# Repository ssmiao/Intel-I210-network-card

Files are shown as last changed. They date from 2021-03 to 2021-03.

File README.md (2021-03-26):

# Intel-I210-network-card
This is a standard PCIe x1 Ethernet Card designed by KiCad.

Before you make it and want to use in your computer, remember to go to DOS system and flash config file to the card. The following steps maybe help.

1. Download [This folder](https://github.com/ssmiao/Intel-I210-network-card)  

2. Use Rufus to create a FreeDOS USB disk (RuFus support itself, you don't need to download a ISO file or something).
3. Copy my folder to the disk.
4. Shutdown the computer and insert the network card
5. Start the computer into FreeDOS system.
6. Go to /FARTHING and run AUTO.BAT

Good luck since I design it 1 year ago and can't remember it clearly. But the hardware can work.

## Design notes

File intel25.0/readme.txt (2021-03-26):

Intel(R) Network Connections Software Version 25.0 Release Notes
================================================================
January 2, 2020

This release includes software and drivers for Intel(R) adapters and integrated 
network connections.

Contents
========

- What's New in This Release
- Discontinued Support
- Configuring SR-IOV for improved network security
- Operating System Support
- Installing Drivers and Intel(R) PROSet for Windows* Device Manager
- User Guides
- Intel Fiber Optic Adapters
- Saving and Restoring Adapter Settings in Microsoft Windows operating systems
- Teaming Notes
- Jumbo Frames
- Power Management and System Wake
- RDMA (Remote Direct Memory Access) Notes
- Microsoft* Windows* 8.1 and Windows Server* 2012 R2 Notes
- Microsoft* Windows Server* 2012 Notes
- Microsoft* Windows* 7 and Windows Server* 2008 R2 Notes
- Intel(R) 710 Series Network Controller Notes
- Intel(R) 10GbE Network Adapter Notes
- Quad Port Server Adapter Notes
- Intel(R) Ethernet Desktop Adapter and Network Connection Notes
- Known Issues
- Customer Support

What's New in This Release
==========================

- Support for the Intel(R) Ethernet Network Adapter X710-T2L for OCP 3.0
- Support for the Intel(R) Ethernet Network Adapter X710-T4L for OCP 3.0

Discontinued Support
====================
Release 24.4 removes the following from the installation package:
- Support for PRO/100 devices
- DOS drivers
- UEFI driver support for PCI/PCI-X devices
- Support for WinCE
- Microsoft* Windows* 10 RS3 (NDIS65) Universal Drivers. Please use the NDIS68 
drivers.
- Support for FCoE
Note: Upgrading to Release 24.4 or later will automatically remove FCoE if it 
was installed in a previous release. Please see BootUtil.txt if you use FCoE 
Boot.

i40evf and ixlv drivers renamed to iavf
---------------------------------------
Release 24.0 renames the i40evf and ixlv drivers to iavf. The i40evf and ixlv 
drivers have been removed from this install media. The iavf drivers can be 
found in the PROAVF directory of this install media.

Discontinued operating systems
------------------------------
Release 24.0 is the last release that supports the following operating systems:
- VMWare* ESX* 6.0 VMKLinux drivers
- VMWare ESX 5.0/5.1

Itanium(R)-based systems are no longer supported
------------------------------------------------
Release 23.5 is the last release that contains any support for Itanium(R)-based 
systems.

Unsupported devices and adapters
--------------------------------
Starting with Release 23.5, the drivers for the following adapters and devices 
will no longer be tested or updated. The drivers may still be provided in your 
download package or on your install media for your convenience.
- Intel(R) 82566MM Gigabit Network Connection
- Intel(R) PRO/1000 PB Dual Port Server Connection
- Intel(R) PRO/1000 EB Network Connection with I/O Acceleration
- Intel(R) PRO/1000 EB1 Network Connection with I/O Acceleration
- Intel(R) PRO/1000 EB Backplane Connection with I/O Acceleration
- Intel(R) 82567V-3 Gigabit Network Connection
- Intel(R) 82567V-4 Gigabit Network Connection
- Intel(R) 82567LM-4 Gigabit Network Connection
- Intel(R) 82567LF Gigabit Network Connection
- Intel(R) 82567V Gigabit Network Connection
- Intel(R) 82567LM-2 Gigabit Network Connection
- Intel(R) 82567LF-2 Gigabit Network Connection
- Intel(R) 82567V-2 Gigabit Network Connection
- Intel(R) 82567LM-3 Gigabit Network Connection
- Intel(R) 82567LF-3 Gigabit Network Connection
- Intel(R) 82577LM Gigabit Network Connection
- Intel(R) 82577LC Gigabit Network Connection
- Intel(R) 82578DM Gigabit Network Connection
- Intel(R) 82578DC Gigabit Network Connection
- Intel(R) 82567LM Gigabit Network Connection
- Intel(R) 82566DM Gigabit Network Connection
- Intel(R) 82566DC Gigabit Network Connection
- Intel(R) 82566MC Gigabit Network Connection
- Intel(R) PRO/1000 PT Dual Port Network Connection
- Intel(R) PRO/1000 PT Dual Port Server Adapter
- Intel(R) PRO/1000 PT Dual Port Server Connection
- Intel(R) PRO/1000 PF Dual Port Server Adapter
- Intel(R) PRO/1000 PT Network Connection
- Intel(R) PRO/1000 PT Server Adapter
- Intel(R) PRO/1000 PF Network Connection
- Intel(R) PRO/1000 PF Server Adapter
- Intel(R) PRO/1000 PB Server Connection
- Intel(R) PRO/1000 PM Network Connection
- Intel(R) PRO/1000 PL Network Connection
- Intel(R) PRO/1000 PT Quad Port Server Adapter
- Intel(R) PRO/1000 PF Quad Port Server Adapter
- Intel(R) PRO/1000 PT Desktop Adapter
- Intel(R) PRO/1000 EB1 Backplane Connection with I/O Acceleration
- Intel(R) PRO/1000 PT Quad Port LP Server Adapter
- Intel(R) 82566DM-2 Gigabit Network Connection
- Intel(R) 82562V 10/100 Network Connection
- Intel(R) 82562V-2 10/100 Network Connection
- Intel(R) 82562G-2 10/100 Network Connection
- Intel(R) 82562GT-3 10/100 Network Connection
- Intel(R) 82562GT-2 10/100 Network Connection
- Intel(R) 82562GT 10/100 Network Connection
- Intel(R) 82562G 10/100 Network Connection
- Intel(R) Gigabit PT Quad Port Server ExpressModule
- Intel(R) 82566DC-2 Gigabit Network Connection
- Intel(R) 82598EB 10 Gigabit AF Dual Port Network Connection
- Intel(R) 10 Gigabit XF SR Dual Port Server Adapter
- Intel(R) 10 Gigabit XF SR Server Adapter
- Intel(R) 82598EB 10 Gigabit AF Network Connection
- Intel(R) 10 Gigabit AT Server Adapter
- Intel(R) 82598EB 10 Gigabit AT Network Connection
- Intel(R) 10 Gigabit AT2 Server Adapter
- Intel(R) 82598EB 10 Gigabit AT2 Network Connection
- Intel(R) 82598EB 10 Gigabit AT CX4 Network Connection
- Intel(R) 10 Gigabit SR Dual Port Express Module
- Intel(R) 10 Gigabit CX4 Dual Port Server Adapter
- Intel(R) 82598EB 10 Gigabit KX4 Network Connection
- Intel(R) 10 Gigabit AF DA Dual Port Server Adapter
- Intel(R) 10 Gigabit XF LR Server Adapter
- Intel(R) 82598EB 10 Gigabit Dual Port Network Connection

Configuring SR-IOV for improved network security
================================================

In a virtualized environment, on Intel(R) Server Adapters that support SR-IOV, 
the virtual function (VF) may be subject to malicious behavior. 
Software-generated frames are not expected and can throttle traffic between the 
host and the virtual switch, reducing performance. To resolve this issue, 
configure all SR-IOV enabled ports for VLAN tagging. This configuration allows 
unexpected, and potentially malicious, frames to be dropped.

Operating System Support
========================

NOTE: Before performing a major OS upgrade, Intel recommends that you uninstall 
the Intel PROSet feature, perform the OS upgrade, and then reinstall with the 
latest version of Intel PROSet. This will ensure all features are available and 
avoid potential issues.

NOTE: Microsoft* Windows Server* 2012 R2 is the last Windows Server operating 
system version that supports Intel(R) Advanced Networking Services (Intel ANS).

NOTE: Intel(R) PROSet for Windows* Device Manager is not supported on 
Microsoft* Windows Server* 2019 (and later) and Microsoft Windows* 10 Version 
1809 (and later). Use Intel(R) PROSet Adapter Configuration Utility instead. 
The installer will determine which utility to install based on the operating 
system you are running.

Intel 10GbE Ethernet Adapters do not support Microsoft* Windows* 32-bit 
operating systems. They support 32-bit versions of Linux* and FreeBSD*.

Even though the UEFI driver states that it supports "Intel(R) 40GbE" devices, 
the driver supports all devices based on the Intel(R) X722, XXV710, X710, and 
XL710 controllers, regardless of speed.

Drivers and Software for unsupported operating systems
------------------------------------------------------
The most recent software and drivers for unsupported operating systems can be 
found on the Intel Customer Support website at
http://www.intel.com/support/go/network/adapter/home.htm

Some older Intel(R) Ethernet Adapters do not have full software support for the 
most recent versions of Microsoft Windows*. Many older Intel Ethernet Adapters 
have base drivers supplied by Microsoft Windows. Lists of supported devices per 
OS are available at:
http://www.intel.com/support/go/network/adapter/nicoscomp.htm

Intel PROSet for Windows Device Manager on older operating systems
------------------------------------------------------------------
On systems running Microsoft Windows 7 and Microsoft Windows Server 2008 R2, 
you must install the legacy version of Intel PROSet for Windows Device Manager. 
If it is available on your install media, Autorun.exe will detect your 
operating system and install the correct drivers and software. For manual 
installs, the software and installers are on your install media in the 
.\APPS\PROSETDX\Win32Legacy, .\APPS\PROSETDX\Winx64Legacy, 
.\APPS\SETUP\SETUPBD\Win32Legacy, and .\APPS\SETUP\SETUPBD\Winx64Legacy 
directories. Note that the legacy version of the software will not change on 
every release.

Installing Drivers and Intel(R) PROSet
======================================

You must have administrator rights to install or use Intel PROSet for Windows 
Device Manager. Intel recommends the following procedure for installing drivers:
1) Cancel any Found New Hardware Wizard screens that open.
2) Start the autorun located on the CD or in your download directory.
3) Click "Install Drivers and Software" and follow the instructions in the
    install wizard.

Intel(R) PROSet functionality is integrated with the Windows Device Manager. To 
configure Intel(R) Ethernet Adapters and Controllers, open the Windows Device 
Manager. Do not open adapter, team, or VLAN properties from the network control 
panel as you may be prompted to reboot your system.

You must upgrade PROSet when upgrading drivers. Failure to do so will result in 
instability and missing tabs in Windows Device Manager.

NOTE: Support for the Intel PROSet command line utilities (prosetcl.exe and
  crashdmp.exe) has been removed. This functionality has been replaced by
  the Intel(R) PROSet for Microsoft* Windows PowerShell* software. Please
   transition all of your scripts and processes to use the Intel PROSet
  for Microsoft Windows PowerShell software. Microsoft* Windows* 8.1
  and Windows Server* 2012 R2 are the last operating systems to support
  the Intel PROSet command line utilities.

Intel PROSet for Windows* Device Manager is not supported on the
following devices
----------------------------------------------------------------
* Intel(R) 82567V-3 Gigabit Network Connection
* Intel(R) X552 10G Ethernet devices
* Intel(R) X552 Virtual Function devices
* Intel(R) X553 Ethernet devices
* Intel(R) X553 Virtual Function devices
* Any platform with a System on a Chip (SoC) processor that includes either
  a server controller (designated by an initial X, such as X552) or both a
  server and client controller (designated by an initial I, such as I218)
* Devices based on the Intel(R) Ethernet Controller X722
* Intel(R) X722 Virtual Function devices

Intel PROSet fails to install
-----------------------------
A possible cause could be the Windows Modules Installer service is disabled. 
The installer for Intel PROSet requires this service. You can enable this 
service from the Administrative Tools -> Component Services control panel.

User Guides
===========

Several user guides for Intel Network Connections are available for this 
product. You may access them in the following ways:
- On Windows-based systems, start the autorun program on the Intel CD,
  then click "View User Guides".
- Double-click "index.htm" located in the root of the Intel CD.
- Go to http://support.intel.com.

Intel Fiber Optic Adapters
==========================

Caution: The fiber optic ports may utilize Class 1 or Class 1M laser devices. 
Do not stare into the end of a fiber optic connector connected to a "live" 
system. Do not use optical instruments to view the laser output. Using optical 
instruments increases eye hazard. Laser radiation is hazardous and may cause 
eye injury. To inspect a connector, receptacle or adapter end, be sure that the 
fiber optic device or system is turned off, or the fiber cable is disconnected 
from the "live" system.

The Intel Gigabit and 10GbE network adapters with fiber optic connections 
operate only at their native speed and only at full-duplex. Therefore you do 
not need to make any adjustments. Use of controls or adjustments or performance 
of procedures other than those specified herein may result in hazardous 
radiation exposure. The laser module contains no serviceable parts.

Saving and Restoring Adapter Settings in Microsoft Windows
operating systems
==========================================================

You can save and then restore adapter settings using the Microsoft* Windows 
PowerShell* script, SaveRestore.ps1. You must have Administration privileges to 
run scripts. If you do not have Administration privileges, you will not receive 
an error; the script just will not run. Only adapter settings are saved 
(including ANS teaming and VLANs). The adapter's driver is not saved. Restore 
using the script only once. Restoring multiple times may result in unstable 
configuration. The Restore operation requires the same OS as when the 
configuration was saved.

NOTE: Intel(R) PROSet for Windows* Device Manager must be installed for
  SaveRestore.ps1 to run. Also, for systems running a 64-bit OS, be sure
  to run the 64-bit version of Windows PowerShell, not the 32-bit (x86)
  version, when running the SaveRestore.ps1 script.

NOTE: Support for the SaveResDX.vbs script is being removed. Please transition
  all of your scripts and processes to Microsoft Windows PowerShell.

NOTE: "Enable RDMA routing across IP Subnets" may not be automatically saved 
when you upgrade from prior versions of the Intel Network Connections software. 
You can manually override the default values within the RDMA Configurations 
Options dialog or via command line properties.

Major Operating system upgrades and saving your configuration
-------------------------------------------------------------
Your network device settings, including teams and VLANs, are not saved when you 
upgrade your operating system. You must reinstall your network drivers and 
software and reconfigure your network devices. This applies for upgrading from 
one version of Microsoft Windows to another, not applying a service pack.

Teaming Notes
=============
Intel devices that are not supported by Intel(R) PROSet can still be added to 
teams. These devices are supported by the Multi-Vendor Teaming functionality of 
ANS teams.

Microsoft Server 2012 NIC Teaming (LBFO)
----------------------------------------
Intel(R) Advanced Network Services (ANS) teaming and VLANs are incompatible 
with Microsoft Server 2012 NIC Teaming (LBFO). Do not create an LBFO team using 
ports that are part of an ANS team or ANS VLAN.

DCB is not compatible with Microsoft Server 2012 NIC Teaming (LBFO)
-------------------------------------------------------------------
Data Center Bridging (DCB) is incompatible with Microsoft Server 2012 NIC 
Teaming (LBFO). Do not create an LBFO team using Intel 10G ports when DCB is 
installed. Do not install DCB if Intel 10G ports are part of an LBFO team. 
Install failures and persistent link loss may occur if DCB and LBFO are used on 
the same port. Installing Microsoft's Hot fix KB 2818790 will resolve the 
issue. This issue only affects Microsoft Windows Server 2012.

RLB is not supported when a team is added to a virtual NIC
----------------------------------------------------------
Virtual NICs cannot be created on a team with Receive Load Balancing enabled. 
Receive Load Balancing is automatically disabled if you create a virtual NIC on 
a team.

Team setup requirement
----------------------
Before creating a team, make sure each adapter is configured similarly. Check 
each adapter's settings in Intel PROSet. Settings to check include QoS Packet 
Tagging, Jumbo Frames, and the various offloads. If team members implement 
Advanced features differently, the team will align the settings with the least 
capable adapter.

Changing Offload Settings for an Adapter in an ANS Team
-------------------------------------------------------
When you disable an offload setting for an adapter in an ANS team, the team 
reloads and the team capabilities are recalculated. As a result, the offload 
setting is disabled for the remaining adapters in the ANS team. Intel PROSet 
does not reflect the fact that the offload setting is disabled for the 
remaining adapters in the team.
If you re-enable the offload setting for the original adapter in the team, the 
settings will not be applied until the system is rebooted or the team is 
reloaded.

IEEE 802.3ad teaming on Cisco trunks
------------------------------------
When implementing 802.3ad teams on Cisco switch ports in trunking mode, set the 
native/untagged VLAN for these ports to ID 1. Otherwise, you may experience 
traffic loss or lack of failover between aggregators. See your Cisco 
documentation for information about setting the native VLAN ID.

Teaming Known Issues
--------------------

Unexpected performance drop or disabled ANS team member
-------------------------------------------------------
Using non-Intel cmdlets, such as the Set-NetAdapterAdvancedProperty cmdlet 
provided in Microsoft PowerShell*, to change settings for an ANS-teamed adapter 
may cause the team to stop using that adapter to pass traffic. You may see this 
as reduced performance or the adapter being disabled in the PROSet Teaming GUI. 
You can repair the issue by changing the setting back to its previous state, or 
by removing the adapter from the ANS team and then adding it back.

Network Connections window shows the team as disabled or network
cable unplugged
----------------------------------------------------------------
After adding a VLAN to the team, this is normal. The connection protocols are 
now bound to the VLAN on the team. You can configure the connection protocols 
in the Properties for the VLAN.

Team name doesn't change in Device Manager
------------------------------------------
If you modify a team name from the team property sheet, it may take several 
minutes for the name to change in Device Manager. Closing and opening Device 
Manager will load the new name.

Removing a teamed adapter from a hot-plug system
------------------------------------------------
When you physically remove an adapter that is part of a team or a VLAN, you 
must reboot or reload the team/VLAN before using that adapter in the same 
network. This will prevent Ethernet address conflicts.

VLANs remain after team removal
-------------------------------
When you remove a team, some of the VLANs bound to that team may remain. You 
can manually remove the VLANs to correct the issue.

Changing speed and duplex of adapters in a team
-----------------------------------------------
When you add an adapter to a Link Aggregation team using Intel PROSet, make 
sure that the adapter is running at the same speed and duplex of the other 
adapters in the team.

Compatibility notes for Multi Vendor Teaming
--------------------------------------------
Attempting to hot-add a non-Intel adapter to a team may cause system 
instability. If you do hot-add a non-Intel adapter to a team, make sure you 
restart the computer or reload the team.

IEEE 802.3ad teaming with Foundry switches
------------------------------------------
Foundry switches require an even number of ports in an aggregated link. If you 
remove an adapter from an 802.3ad team connected to a Foundry switch, make sure 
you maintain an even number of adapters in the team.

Jumbo Frames and Jumbo Packets
==============================

Jumbo Frames and MACSec are not compatible on the Intel(R) 82579LM and Intel(R) 
82579V Network Connections. If MACSec is enabled on a platform containing 
either part, you will not be able to enable Jumbo Frames on the connection.

Limited Jumbo Frame Size
------------------------
Some Intel gigabit adapters and connections that support Jumbo Frames have a 
frame size limit of 4K bytes. The following devices have this limitation:
  Intel(R) 82577LM Gigabit Network Connection
  Intel(R) 82578DM Gigabit Network Connection

The following devices do not support jumbo frames:
  Intel(R) PRO/1000 Gigabit Server Adapter
  Intel(R) PRO/1000 PM Network Connection
  Intel(R) 82562V 10/100 Network Connection
  Intel(R) 82562GT 10/100 Network Connection
  Intel(R) 82566DM Gigabit Network Connection
  Intel(R) 82566DC Gigabit Network Connection
  Intel(R) 82566DC-2 Gigabit Network Connection
  Intel(R) 82562V-2 10/100 Network Connection
  Intel(R) 82562G-2 10/100 Network Connection
  Intel(R) 82562GT-2 10/100 Network Connection
  Intel(R) 82567LF Gigabit Network Connection
  Intel(R) 82567V Gigabit Network Connection
  Intel(R) 82567LF-2 Gigabit Network Connection
  Intel(R) 82567V-2 Gigabit Network Connection
  Intel(R) 82567LF-3 Gigabit Network Connection
  Intel(R) 82552 10/100 Network Connection
  Intel(R) 82577LC Gigabit Network Connection
  Intel(R) 82578DC Gigabit Network Connection
  Intel(R) 82567V-3 Gigabit Network Connection
  Intel(R) 82567V-4 Gigabit Network Connection

The Intel PRO/1000 PL Network Connection supports jumbo frames in Microsoft* 
Windows* operating systems only when Intel(R) PROSet for Windows Device Manager 
is installed.

Power Management and System Wake
================================

Not all systems support every wake setting. There may be BIOS or Operating 
System settings that need to be enabled for your system to wake up. In 
particular, this is true for Wake from S5 (also referred to as Wake from power 
off). Microsoft Windows 7 and Windows Server 2008 R2 do not support Wake on 
directed packet. Systems with these operating systems will not wake on a ping 
or other directed packet.

System does not wake when expected
----------------------------------
Under Microsoft Windows 7 or Windows Server 2008 R2, the system may not wake 
when sent an ARP packet. Forcing your system into Home Networking mode (instead 
of work or public mode) will resolve the issue. You can set the network mode 
during install or from the Networking Control Panel.
However, if the network is disconnected and reconnected, and a DHCP server is 
not available or if there is no default gateway defined, it appears to the 
operating system that the network is undefined and the OS will reset it to 
public.

Under Microsoft Windows Server 2012, the system may not wake even though Wake 
on LAN settings are enabled. Disabling Fast Startup in the operating system 
should resolve the issue.

System does not wake on link
----------------------------
On a driver-only installation, if you change 'Wake on Link Settings' to Forced 
and change 'Wake on Magic Packet' and 'Wake on Pattern Match' to Disabled, the 
system may not wake up when expected. In order to "Wake on Link" successfully, 
check the Power Management tab and make sure that "Allow this device to wake 
the computer" is checked. You may also need to change 'Wake on Magic Packet' or 
'Wake on Pattern Match' to Enabled.
On Microsoft* Windows* 7, or later, you must enable Wake on Magic Packet or 
Wake on Pattern Match for Wake on Link to function properly.

Directed Packets may not wake the system
----------------------------------------
On some systems, quad port server adapters may not wake when configured to wake 
on directed packet. If you experience problems waking on directed packets, you 
must configure the adapter to use Magic Packets*.

Power Management options are unavailable or missing
---------------------------------------------------
If you install only the base drivers, later install Intel(R) PROSet for Windows 
Device Manager, then remove Intel PROSet, the settings on the Power Management 
tab on the Adapter Property Sheet may be unavailable or missing altogether. You 
must reinstall Intel PROSet to resolve the issue.

Low power link speed slower than expected
-----------------------------------------
If you disable the "Reduce Power During Standby" setting and remove power from 
the system, your system may link at 10Mbps when power is restored, instead of 
100Mbps or faster. The system will continue to link at 10Mbps until the 
operating system is loaded. This setting will be restored when the OS loads.

System Wakes Unexpectedly
-------------------------
On a driver only install, if you uncheck the "Allow this device to bring the 
computer out of standby" option on the Power Management tab, the adapter will 
still wake the system from Standby or Hibernate. The "Wake on Settings" option 
on the Advanced tab must also be set to Disabled.

Auto Connect Battery Saver (ACBS) enabled NICs do not power up when
connected back to back
-------------------------------------------------------------------
If you have two systems, both running on batteries and both with ACBS-enabled 
NICs that are in an ACBS state, and you connect them back to back, the NICs 
will not power up. Since both NICs are powered down, neither one can generate a 
link signal to wake the other. Either connect AC power to one system or disable 
ACBS to resolve this issue.

Auto Connect Battery Saver (ACBS) does not function
---------------------------------------------------
ACBS will not function on an adapter if the adapter has forced speed or duplex 
settings. ACBS will only function if the adapter is set to auto-detect or 
auto-negotiate.

Wake on LAN is unavailable
--------------------------
Wake on LAN is supported on port A only on the following devices:
- Intel(R) PRO/1000 GT Quad Port Server Adapter
- Intel(R) PRO/1000 PT Quad Port Server Adapter
- Intel(R) PRO/1000 PT Dual Port Network Connection
- Intel(R) PRO/1000 PT Dual Port Server Connection
- Intel(R) PRO/1000 PT Dual Port Server Adapter
- Intel(R) PRO/1000 PF Dual Port Server Adapter
- Intel(R) PRO/1000 PT Quad Port LP Server Adapter
- Intel(R) PRO/1000 PF Quad Port Server Adapter
- Intel(R) Gigabit ET2 Quad Port Server Adapter
- Intel(R) Ethernet Server Adapter I340-T4
- Intel(R) Ethernet Server Adapter I340-T2
- Intel(R) Gigabit ET Quad Port Server Adapter
- Intel(R) Gigabit EF Dual Port Server Adapter
- Intel(R) Gigabit ET Dual Port Server Adapters
- Intel(R) Gigabit VT Quad Port Server Adapter
- Intel(R) Ethernet Server Adapter I340-F4
Wake on LAN is not supported on any port of the following devices:
- Intel(R) Ethernet Converged Network Adapter X710
- Intel(R) Ethernet Converged Network Adapter X710-2
- Intel(R) Ethernet Converged Network Adapter X710-4
- Intel(R) Ethernet Converged Network Adapter X710-T
- Intel(R) Ethernet Converged Network Adapter X710-T4
- Intel(R) Ethernet Converged Network Adapter XL710-Q1
- Intel(R) Ethernet Converged Network Adapter XL710-Q2
- Intel(R) Ethernet Network Adapter X710-T2L
- Intel(R) Ethernet Network Adapter X710-T4L
- Intel(R) Ethernet Network Adapter X710-TL

Most Intel 10GbE Network Adapters do not support Wake on LAN on any port. The 
Intel(R) Ethernet Converged Network Adapter X550-T1 and Intel(R) Ethernet 
Converged Network Adapter X550-T2 have a manageability/AUX power connector. 
These devices only support WoL if AUX power is supplied via this connector. 
Note that this is system and adapter specific. Some with this connector do not 
support WoL. Some systems do not provide the correct power connection. See your 
system documentation for details.

System Wakes-Up from a Removed VLAN
-----------------------------------
If a system goes into standby mode, and a directed packet is sent to the IP 
address of the removed VLAN, the system will wake-up. This occurs because a 
directed packet bypasses VLAN filtering.

Intel Network Adapters ignore consecutive Wake Up signals while
transitioning into standby mode
---------------------------------------------------------------
While sending a system into standby, occasionally a wake up packet arrives 
before the system completes the transition into standby mode. When this 
happens, the system ignores consecutive wake up signals and remains in standby 
mode until manually powered up using the mouse, keyboard, or power button.

Link flap when Energy Efficient Ethernet is enabled
---------------------------------------------------
Some switches do not support Energy Efficient Ethernet (EEE) correctly. Make 
sure your switch is loaded with the latest firmware. Disabling EEE on your 
adapter may resolve this issue.

Microsoft Windows* 8.1 and Windows Server* 2012 R2 Notes
========================================================

Some older Intel(R) Ethernet Adapters do not have full software support for the 
most recent versions of Microsoft Windows*. Many older Intel Ethernet Adapters 
have base drivers supplied by Microsoft Windows. Lists of supported devices per 
OS are available at:
http://www.intel.com/support/go/network/adapter/nicoscomp.htm

Encapsulated traffic may fail when traffic is tagged and 'Packet
Priority & VLAN' option is disabled
----------------------------------------------------------------
If the 'Packet Priority & VLAN' advanced parameter is set to "Disabled," VLAN 
tagged packets will have incomplete destination information and may be dropped 
by the physical switch. To ensure encapsulated traffic is not dropped, verify 
that the 'Packet Priority & VLAN' advanced parameter is set to "Enabled."

Virtual Machine Queues are not allocated until reboot
-----------------------------------------------------
On a Microsoft Windows Server 2012 R2 system with Intel(R) Ethernet Gigabit 
Server adapters installed, if you install Hyper-V and create a VM switch, 
Virtual Machine Queues (VMQ) are not allocated until you reboot the system. 
Virtual machines can send and receive traffic on the default queue, but no VMQs 
will be used until after a system reboot.

Link loss after changing the Jumbo Frames setting
-------------------------------------------------
Inside a guest partition on a Microsoft Windows Server 2012 R2 Hyper-V virtual 
machine, if you change the jumbo frame Advanced setting on an Intel(R) X540 
based Ethernet Device or associated Hyper-V NetAdapter, you may lose link. 
Changing any other Advanced Setting will resolve the issue.

DCB QoS and Priority Flow Control do not act as expected
--------------------------------------------------------
If you use Microsoft's Datacenter Bridging (DCB) implementation configure 
Quality of Service (QoS) and Priority Flow Control (PFC), the actual traffic 
flow segregation per traffic class may not match your configuration and PFC may 
not pause traffic as expected. If you mapped more than one priority to a 
Traffic Class, enabling only one of the priorities and disabling the others 
will work around the issue. Installing Intel's DCB implementation will also 
resolve this issue.
This issue affects Microsoft Windows Server 2012 and Server 2012 R2.

Microsoft* Windows Server* 2012 Notes
=====================================

Some older Intel(R) Ethernet Adapters do not have full software support for the 
most recent versions of Microsoft Windows*. Many older Intel Ethernet Adapters 
have base drivers supplied by Microsoft Windows. Lists of supported devices per 
OS are available at:
http://www.intel.com/support/go/network/adapter/nicoscomp.htm

Hot plug operations do not work as expected in the following reference designs:
Foxcove - Hot plug operations do not work.
Emerald Ridge - Hot plug operations work only if you have the latest BIOS.

In Intel(R) PROSet for Windows Device Manager, the help text may not initially 
be displayed. The text should appear after switching between tabs a few times 
in Intel(R) PROSet.

DCB QoS and Priority Flow Control do not act as expected
--------------------------------------------------------
If you use Microsoft's Datacenter Bridging (DCB) implementation configure 
Quality of Service (QoS) and Priority Flow Control (PFC), the actual traffic 
flow segregation per traffic class may not match your configuration and PFC may 
not pause traffic as expected. If you mapped more than one priority to a 
Traffic Class, enabling only one of the priorities and disabling the others 
will work around the issue. Installing Intel's DCB implementation will also 
resolve this issue.
This issue affects Microsoft Windows Server 2012 and Server 2012 R2.

Microsoft Windows* 7 and Windows Server* 2008 R2 Notes
======================================================

Microsoft Windows 7 and Windows Server 2008 R2 do not support Wake on directed 
packet. Systems with these operating systems will not wake on a ping or other 
directed packet.

Some older Intel(R) Ethernet Adapters do not have full software support for the 
most recent versions of Microsoft Windows*. Many older Intel Ethernet Adapters 
have base drivers supplied by Microsoft Windows. Lists of supported devices per 
OS are available at:
http://www.intel.com/support/go/network/adapter/nicoscomp.htm

Flow Control is off by default
------------------------------
The inbox drivers for Intel network devices in Windows 7 and Windows Server 
2008 R2 have flow control turned off by default.

Intel(R) 710 Series Network Controller Notes
============================================

In order for an Intel(R) 40GbE Network Adapter to reach its full potential, you 
must install it in a PCIe Gen3 x8 slot. Installing it in a shorter slot, or a 
Gen2 or Gen1 slot, will impact the throughput the adapter can attain.

Some Intel(R) 710 series based devices report a subvendor ID of 0x0000 and may 
display a generic branding string. Port 0 reports the correct subvendor ID and 
displays the correct branding string.

Intel 710 series based devices may maintain link on any and all ports as long 
as power is provided to the device, regardless of the device's or system's 
power state.

Intel 710 series based devices do not support Microsoft Windows Server 2008R2 
or Windows Server 2012 as SR-IOV Guest operating systems. These devices do not 
support Windows Server 2012 as the SR-IOV Host operating system. They also do 
not support Linux as the SR-IOV guest operating system on any Microsoft Windows 
Server Hyper-V Host.

SFP+ and QSFP+ Devices:

See the link below for information on supported media for X710/XL710/XXV710 
based devices:
  http://www.intel.com/content/dam/www/public/us/en/documents/release-notes/
  xl710-ethernet-controller-feature-matrix.pdf
NOTES:
* Some Intel branded network adapters based on the X710/XL710 controller
  only support Intel branded modules. On these adapters, other modules
  are not supported and will not function.
* For connections based on the 710 series controller, support is dependent
  on your system board. Please see your vendor for details.
* In all cases Intel recommends using Intel optics; other modules may function
  but are not validated by Intel. Contact Intel for supported media types.
* In systems that do not have adequate airflow to cool the adapter and
  optical modules, you must use high temperature optical modules.

Intel ANS VLANs adversely affect performance
--------------------------------------------
Intel ANS VLANs adversely affect the performance of 710 series based devices. 
Use the networking features built into Microsoft Windows Server 2012, or other 
server management software, to assign VLANs.

Diagnostic button disabled
--------------------------
When part of an Intel(R) ANS team, devices based on the Intel X710/XL710 
controller do not support diagnostics. Support will be added in a future 
release.

Traffic is not passed between Virtual NICs
------------------------------------------
SR-IOV Virtual Functions are unable to send or receive traffic between Virtual 
NICs on the same physical port or between emulated connections on a Linux 
Software bridge and connections that use SR-IOV VFs. Use an external switch 
that is 802.1Qbg (VEPA) capable to workaround this issue.

Intel 10GbE Network Adapter Notes
=================================

Release 18.7 is the last release in which Intel 10GbE Network Adapters support 
32-bit Microsoft Windows. Starting with Release 18.8, Intel 10GbE Network 
Adapters only support 64-bit operating systems.

Devices based on the Intel(R) Ethernet Connection X552 and Intel(R) Ethernet 
Connection X553 do not support the following features:
* Energy Efficient Ethernet (EEE)
* Intel PROSet for Windows Device Manager
* Intel ANS teams or VLANs (LBFO is supported)
* Data Center Bridging (DCB)
* IPSec Offloading
* MACSec Offloading
In addition, SFP+ devices based on the Intel(R) Ethernet Connection X552 and 
Intel(R) Ethernet Connection X553 do not support the following features:
* Speed and duplex auto-negotiation.
* Wake on LAN
* 1000BASE-T SFP Modules

Devices based on the Intel(R) Ethernet Controller X722 do not support the 
following features:
* Intel PROSet for Windows Device Manager
* Intel ANS teams or VLANs (LBFO is supported)

Attaching the cable to the Intel(R) 10 Gigabit AF DA Dual Port Server Adapter 
may require significant force. The cable must be latched in for proper 
operation.

When 82599-based SFP+ devices are connected back to back, they should be set to 
the same Speed/Duplex setting. Results may vary if you mix speed settings.

Some Intel(R) 10 Gigabit Network Adapters and Connections support SFP+ 
pluggable optical modules.

82599-Based Adapters
NOTES:
* If your 82599-based Intel(R) Network Adapter came with Intel SFP+ optics, or 
is an Intel(R) Ethernet Server Adapter X520 type of adapter, then it only 
supports Intel optics and/or the direct attach cables listed below.

Supplier	Type					Part Numbers
SR Modules
  Intel		DUAL RATE 1G/10G SFP+ SR (bailed)	AFBR-703SDZ-IN2
  Intel		DUAL RATE 1G/10G SFP+ SR (bailed)	FTLX8571D3BCV-IT
  Intel		DUAL RATE 1G/10G SFP+ SR (bailed)	AFBR-703SDDZ-IN1
LR Modules
  Intel		DUAL RATE 1G/10G SFP+ LR (bailed)	FTLX1471D3BCV-IT
  Intel		DUAL RATE 1G/10G SFP+ LR (bailed)	AFCT-701SDZ-IN2
  Intel		DUAL RATE 1G/10G SFP+ LR (bailed)	AFCT-701SDDZ-IN1
QSFP Modules
  Intel		TRIPLE RATE 1G/10G/40G QSFP+ SR (bailed)    E40GQSFPSR
QSFP+ 40G speed is not supported on 82599 based devices.

The following is a list of 3rd party SFP+ modules and direct attach cables that 
have received some testing. Not all modules are applicable to all devices.

Supplier	Type				Part Numbers
  Finisar	SFP+ SR bailed, 10g single rate	FTLX8571D3BCL
  Avago		SFP+ SR bailed, 10g single rate	AFBR-700SDZ
  Finisar	SFP+ LR bailed, 10g single rate	FTLX1471D3BCL

  Finisar	DUAL RATE 1G/10G SFP+ SR (No Bail)	 FTLX8571D3QCV-IT
  Avago		DUAL RATE 1G/10G SFP+ SR (No Bail)	AFBR-703SDZ-IN1
  Finisar	DUAL RATE 1G/10G SFP+ LR (No Bail)	FTLX1471D3QCV-IT
  Avago		DUAL RATE 1G/10G SFP+ LR (No Bail)	AFCT-701SDZ-IN1

  Finisar	1000BASE-T SFP				FCLF8522P2BTL
  Avago		1000BASE-T				SFP ABCU-5710RZ
  HP		1000BASE-SX				SFP 453153-001

82599-Based SFP+ adapters support all passive and active limiting direct attach 
cables that comply with SFF-8431 v4.1 and SFF-8472 v10.4 specifications.

82599-Based QSFP+ Adapters
NOTES:
* 82599-Based QSFP+ adapters do not support 1x40Gbps connections. They only
  support 4x10Gbps connections. QSFP+ link partners must be configured for
  4x10Gbps.
* 82599-Based QSFP+ adapters do not support automatic link speed detection.
  The adapter's link speed must be configured to either 10Gbps or 1Gbps to
  match the link partners speed capabilities. Incorrect speed configurations
  will result in failure to link.

The Intel(R) Ethernet Converged Network Adapter X520-Q1 only supports the 
optics and direct attach cables listed below.

Supplier	Type					Part Numbers
  Intel		DUAL RATE 1G/10G QSFP+ SR (bailed)	E40GQSFPSR

82599-Based QSFP+ adapters support all passive and active limiting QSFP+ direct 
attach cables that comply with SFF-8436_v4.1 specifications.

82598-Based Adapters
NOTES:
* Intel(R) Network Adapters that support removable optical modules
  only support their original module type (i.e., the Intel(R) 10 Gigabit
  SR Dual Port Express Module only supports SR optical modules). If you
  plug in a different type of module, the driver will not load.
* Hot Swapping/hot plugging optical modules is not supported.
* Only single speed, 10 gigabit modules are supported.
* LAN on Motherboard (LOMs) may support DA, SR, or LR modules. Other
  module types are not supported. Please see your system documentation for
  details.

The following is a list of SFP+ modules and direct attach cables that have 
received some testing. Not all modules are applicable to all devices.

Supplier	Type				Part Numbers
  Finisar	SFP+ SR bailed, 10g single rate	FTLX8571D3BCL
  Avago		SFP+ SR bailed, 10g single rate	AFBR-700SDZ
  Finisar	SFP+ LR bailed, 10g single rate	FTLX1471D3BCL

82598-Based adapters support direct attach cables that comply with SFF-8431 
v4.1 and SFF-8472 v10.4 specifications with the following exceptions:

Supplier	Type					Part Numbers
  Leoni		3 meter passive direct attach cable	747522301
  Amphenol	3 meter passive direct attach cable	571540002

*** Active direct attach cables are not supported.

THIRD PARTY OPTIC MODULES AND CABLES REFERRED TO ABOVE ARE LISTED ONLY FOR THE 
PURPOSE OF HIGHLIGHTING THIRD PARTY SPECIFICATIONS AND POTENTIAL COMPATIBILITY, 
AND ARE NOT RECOMMENDATIONS OR ENDORSEMENT OR SPONSORSHIP OF ANY THIRD PARTY'S 
PRODUCT BY INTEL. INTEL IS NOT ENDORSING OR PROMOTING PRODUCTS MADE BY ANY 
THIRD PARTY AND THE THIRD PARTY REFERENCE IS PROVIDED ONLY TO SHARE INFORMATION 
REGARDING CERTAIN OPTIC MODULES AND CABLES WITH THE ABOVE SPECIFICATIONS. THERE 
MAY BE OTHER MANUFACTURERS OR SUPPLIERS, PRODUCING OR SUPPLYING OPTIC MODULES 
AND CABLES WITH SIMILAR OR MATCHING DESCRIPTIONS. CUSTOMERS MUST USE THEIR OWN 
DISCRETION AND DILIGENCE TO PURCHASE OPTIC MODULES AND CABLES FROM ANY THIRD 
PARTY OF THEIR CHOICE. CUSTOMERS ARE SOLELY RESPONSIBLE FOR ASSESSING THE 
SUITABILITY OF THE PRODUCT AND/OR DEVICES AND FOR THE SELECTION OF THE VENDOR 
FOR PURCHASING ANY PRODUCT. THE OPTIC MODULES AND CABLES REFERRED TO ABOVE ARE 
NOT WARRANTED OR SUPPORTED BY INTEL. INTEL ASSUMES NO LIABILITY WHATSOEVER, AND 
INTEL DISCLAIMS ANY EXPRESS OR IMPLIED WARRANTY, RELATING TO SALE AND/OR USE OF 
SUCH THIRD PARTY PRODUCTS OR SELECTION OF VENDOR BY CUSTOMERS.

Intel 10GbE Network Adapter Known Issues
-----------------------------------------

ETS Bandwidth Allocations Don't Match Settings
----------------------------------------------
When Jumbo Frames is set to 9K with a 10GbE adapter, a 90%/10% ETS traffic 
split will not actually be attained on any particular port, despite settings 
being made on the DCB switch. When ETS is set to a 90%/10% split, an actual 
observed split of 70%/30% is more likely.

Supported SFP, SFP+, or QSFP+ module not recognized by the system
-----------------------------------------------------------------
If you try to install an unsupported module, the port may no longer install any 
subsequent modules, regardless of whether the module is supported or not. The 
port will show a yellow bang under Windows Device manager and an event id 49 
(unsupported module) will be added to the system log when this issue occurs. To 
resolve this issue, the system must be completely powered off.

Lower than expected performance on quad port 10GbE devices
----------------------------------------------------------
All SFP and QSFP quad port NICs based on the 82599 controller will link at 5 
GB/s (PCIe gen2) when used in a system from Intel's Enterprise Platforms and 
Services Division (EPSD). The PLX PCIe switch used on these NICs is not on the 
EPSD white list of supported PCIe gen3 devices. Devices not on the white list 
are blocked from linking at PCIe gen3 by the production BIOS.

Lower than expected performance on quad port 10GbE devices
----------------------------------------------------------
Quad port 10Gbe devices require x8 PCIe gen 3 slots. Full throughput is not 
possible in a PCIe gen 2 slot.

Lower than expected performance on dual port 10GbE devices
----------------------------------------------------------
Some PCIe x8 slots are actually configured as x4 slots. These slots have 
insufficient bandwidth for full 10Gbe line rate with dual port 10GbE devices. 
The driver can detect this situation and will write the following message in 
the system log: "PCI-Express bandwidth available for this card is not 
sufficient for optimal performance. For optimal performance a x8 PCI-Express 
slot is required." If this error occurs, moving your adapter to a true x8 slot 
will resolve the issue.

Link Loss on 10GbE Devices with Jumbo Frames enabled
----------------------------------------------------
You must not lower Receive_Buffers or Transmit_Buffers below 256 if jumbo 
frames are enabled on an Intel(R) 10GbE Device. Doing so will cause loss of 
link.

Failed connection and possible system instability
-------------------------------------------------
If you have non-Intel networking devices capable of Receive-Side Scaling 
installed in your system, the Microsoft Windows registry keyword "RSSBaseCPU" 
may have been changed from the default value of 0x0 to point to a logical 
processor. If this keyword has been changed then devices based on Intel(R) 
82598 or 82599 10 Gigabit Ethernet Controllers might not pass traffic. 
Attempting to make driver changes in this state may cause system instability. 
Set the value of RSSBaseCpu to 0x0, or to a value corresponding to a physical 
processor, and reboot the system to resolve the issue.

1GbE Quad Port Server Adapter Notes
===================================

Hot Plug operations are not supported by the following Intel Quad Port Server 
Adapters:
Intel(R) Gigabit ET2 Quad Port Server Adapter
Intel(R) Gigabit ET Quad Port Server Adapter
Intel(R) Gigabit VT Quad Port Server Adapter
Intel(R) PRO/1000 PF Quad Port Server Adapter
Intel(R) PRO/1000 PT Quad Port LP Server Adapter
Intel(R) PRO/1000 PT Quad Port Server Adapter
Intel(R) PRO/1000 GT Quad Port Server Adapter
Intel(R) PRO/1000 MT Quad Port Server Adapter

System does not boot
--------------------
Your system may run out of I/O resources and fail to boot if you install more 
than four quad port server adapters. Moving the adapters to different slots or 
rebalancing resources in the system BIOS may resolve the issue.
This issue affects the following Adapters:
* Intel(R) Ethernet Server Adapter I350-T4
* Intel(R) Gigabit ET2 Quad Port Server Adapter
* Intel(R) Gigabit ET Quad Port Server Adapter
* Intel(R) Gigabit VT Quad Port Server Adapter
* Intel(R) PRO/1000 PF Quad Port Server Adapter
* Intel(R) PRO/1000 PT Quad Port LP server Adapter

Intel PRO/1000 GT Quad Port Server Adapter Not recommended
for use on some systems
----------------------------------------------------------
The Intel PRO/1000 GT Quad Port Server Adapter does not function correctly in 
the following systems:

* SuperMicro* P4DP6 running SCO Unixware or OpenServer 6
* Intel(R) Server Board SE7505VB2 based systems (PCI slot 5 only. Other slots 
work as designed)

Code 10 on Intel(R) PRO/1000 PT Quad Port LP Server Adapter
-----------------------------------------------------------
You may encounter a Windows Code 10 error with an Intel(R) PRO/1000 PT Quad 
Port LP Server Adapter installed in slot #4 of a SuperMicro 7046T-H6R system. 
Moving the adapter to another slot will resolve the issue.

Intel PRO/1000 MT Quad Port Server Adapter Known Issues
-------------------------------------------------------
The Intel PRO/1000 MT Quad Port Server Adapter operates in 3.3 volt PCI-X slots 
only. For best performance, this adapter should be installed in a 64-bit PCI-X 
slot. Refer to the detailed installation instructions in the User's Guide for 
additional requirements.

Wake on LAN is not supported on the Intel PRO/1000 MT Quad Port Server Adapter. 
Trying to enable this feature with IBAUTIL.EXE will not have any effect.

The Intel PRO/1000 MT Quad Port Server Adapter supports Intel(R) Boot Agent 
functionality on ports A and B, however it is disabled by default. To enable 
and use the Intel Boot Agent, refer to the User's Guide and other information 
in the \APPS\BOOTAGNT\ directory.

Multiple Intel PRO/1000 MT Quad Port Server Adapters in one system
------------------------------------------------------------------
Installing more than two Intel PRO/1000 MT Quad Port Server Adapters in the 
same system is not recommended. Many systems are unable to support the power 
requirements for more than two of these adapters.

Use only in a PCI-X Slot
------------------------
Reduced performance has been observed when the Intel PRO/1000 MT Quad Port 
Server Adapter is installed in a slot other than a PCI-X slot.

Shared Interrupt Limitation
---------------------------
In some systems, the BIOS and OS assign the same interrupt number to two or 
more different ports on the Intel PRO/1000 MT Quad Port Server Adapter. If this 
occurs, these ports do not function properly. To address this issue, reassign 
the system resources so that each port of the adapter has its own unique 
interrupt number or disable one of the ports sharing the same interrupt number.

Downshifting
------------
When connecting to any Gigabit switch via a faulty CAT 5 cable where one pair 
is broken, the adapter does not downshift from 1 Gig to 100Mbps. For the 
adapter to downshift, it must identify two broken pairs in the cable.

Intel PRO/1000 MT Quad Port Server Adapter Not recommended
for use on some systems
----------------------------------------------------------
The Intel PRO/1000 MT Quad Port Server Adapter does not function correctly in 
the following systems:

Dell* PowerEdge* 2500
Dell PowerEdge 6400
Dell PowerEdge 6450
Dell PowerEdge 6650SC
Intel Saber, Saber-R, and Saber-Rx Systems
SuperMicro 370DE6
SuperMicro P4DP6
IBM* eServer* xSeries* 365

Using the Intel PRO/1000 MT Quad Port Server Adapter in these configurations is 
not recommended.

Heavy traffic may cause system reboot in some systems
-----------------------------------------------------
Using an Intel PRO/1000 MT Quad Port Server Adapter may cause a reboot in 
systems with the Intel Profusion chipset including: Intel OCPRF100 and SRPM8 
server systems; Compaq* ProLiant* 8000, 8500, ML750, DL760; Dell PowerEdge 
8450, 6300, 6350; IBM* x370. Using the Intel PRO/1000 MT Quad Port Server 
Adapter in these configurations is not recommended.

Intel(R) Ethernet Desktop Adapter and Network Connection Notes
==============================================================

The Intel(R) 82562V 10/100 Network Connection and Intel(R) 82562V 10/100 
Network Connection are supported by the gigabit drivers.

Release 20.6 is the last release in which Intel(R) Ethernet iSCSI Boot supports 
Intel(R) Ethernet Desktop Adapters and Network Connections. Starting with 
Release 20.7, Intel Ethernet iSCSI Boot no longer supports Intel Ethernet 
Desktop Adapters and Network Connections.

Known Issues
============

Lower than expected receive throughput in Windows Hyper-V* guests 
-----------------------------------------------------------------
You may experience lower than expected receive throughput in Windows guest VMs 
when VMQ offload is enabled. Disabling Receive Segment Coalescing (RSC) in the 
network adapter's advanced settings may help resolve the issue.

Logical switch creation fails
-----------------------------
When you use Microsoft SCVMM (System Center Virtual Machine Manager) to create 
an encapsulation-enabled (VXLAN, NVGRE, etc.) logical switch, it may fail with 
error code 0x80041001. To resolve the issue, after the failure is seen, perform 
the following:
1. Disable the "Hyper-V Extensible Virtual Switch" property on the Intel 
Ethernet device.
2. Recreate the logical switch.
This affects hosts running Microsoft* Windows Server* 2019.

Microsoft Windows guest operating systems may not pass traffic across VLANs
---------------------------------------------------------------------------
The Virtual Function (VF) driver is not aware of the VLAN configuration if you 
use LBFO (Load Balancing and Failover) to configure VLANs in a Windows guest. 
VLANs configured using LBFO on a Virtual Function driver may result in failure 
to pass traffic.

Log link state events do not display correctly in localized Windows Server 2016
-------------------------------------------------------------------------------
In a previous version of the driver, some log link state events did not display 
correctly in some localized versions of Microsoft* Windows Server* 2016 when 
bringing link down and then back up on Intel(R) i210AT adapters. This issue has 
been corrected in the current driver version. Be sure to download and install 
the latest drivers and software from Intel.

Unexpected CPU utilization
--------------------------
You may see one CPU reaching 90%-100% utilization if the RSS Load Balancing 
Profile is set to NUMAScalingStatic. Setting the RSS Load Balancing Profile to 
ClosestProcessor should correctly balance the CPU load. This issue affects 
devices based on the Intel(R) Ethernet Controller X722 in systems running 
Microsoft* Windows Server* 2019.

NVM update utilities exit with error on kernel 4.16 and higher 
--------------------------------------------------------------
On Linux* kernel 4.16 and higher, the iomem parameter is set to "strict" by 
default, which prevents the NVM update utilities from accessing the MMIO on 
1GbE and 10GbE devices. Trying to update a device when "strict" is set causes 
the device to lose link during the update process. Also, if you run any of the 
NVM update utilities (NVMUpdate, NVMCheck, QCU, or Bootutil), the utility may 
exit with the error "The selected adapter (location:[Bus:Device:Function]) 
cannot be initialized due to inaccessible device memory. Update the device 
driver and reboot the system before running this utility again. Consult the 
utility documentation for more information." 

If you wish to update a device without losing link, you can either:
1. Install Linux base drivers (igb or ixgbe) from Release 24.1, or newer
2. Set the iomem kernel parameter to "relaxed" (i.e., iomem=relaxed) and reboot 
the system before running the update utility.

Device becomes unresponsive after Hardware diagnostics failure 
--------------------------------------------------------------
If you have Data Center Bridging (DCB) enabled on your system, hardware 
diagnostics may fail even if no hardware issue exists. This may cause the 
device to stop responding. Reloading the driver will resolve this issue. 
Disabling DCB and rerunning hardware diagnostics will display the correct 
pass/fail results for the device.

Incorrect branding strings
--------------------------
Devices based on the Intel(R) Ethernet Controller X550 and Intel Ethernet 
Controller X700 series may display incorrect branding strings in Windows Device 
Manager. This issue does not affect the functionality of the device. This issue 
only affects Microsoft* Windows Server* 2016.

Identify Adapter command does not blink LEDs as expected
--------------------------------------------------------
On some Intel(R) Ethernet Connections, the LEDs are connected to PHY and not to 
the MAC. The driver's Identify Adapter functionality uses the MAC register, so 
the LEDs will not blink on these devices. This affects the following devices:
*  Intel(R) Ethernet Connection X552 1000BASE-T
*  Intel(R) Ethernet Connection X552/X557-AT 10GBASE-T

Changing a VLAN ID to untagged and then reusing that VLAN ID may cause the
untagged VLAN to fail
--------------------------------------------------------------------------
On Windows 10 RS1, if you change a VLAN ID to untagged on a device or team and 
then later reuse that VLAN ID on that device or team, the untagged VLAN may 
fail to pass traffic. To resolve this issue, remove the untagged VLAN and 
recreate it.

VXN Driver Fails To Load in Windows Server VM on ESX 6.5
--------------------------------------------------------
The VXN driver may fail to load with a yellow-bang error after installation on 
a Windows Server 2016 or Windows Server 2012 R2 VM running on an ESX 6.5 host. 
To fix this, reboot the VM.

Driver Installation Hangs
-------------------------
Driver installation for devices based on the Intel Ethernet X710 and XL710 
controllers may hang. This may be because the device is connected to a switch 
that is not advertising traffic class 0. To resolve the issue, disconnect the 
device from the switch or configure the switch to advertise TC0, power cycle 
your system, then restart the driver installation. This may occur with any 
Intel Ethernet X710 or XL710 device on Microsoft Windows Server 2016.

Device Fails to Load
--------------------
Devices based on the Intel Ethernet X710, XL710, X722, and XXV710 controllers 
may fail to load with a yellow-bang error. This may be because the device is 
connected to a switch that is not advertising traffic class 0. To resolve the 
issue, disconnect the device from the switch or configure the switch to 
advertise TC0, and restart your system. This may occur with any Intel Ethernet 
X710, XL710, X722, or XXV710 device on any version of Microsoft Windows Server.

Import of IntelNetCmdlets PowerShell Module Fails When Trailing
Backslash Used
----------------------------------------------------------------
If you include a trailing backslash ("\") at the end of the Import-Module 
command, the import operation will fail (for example, "ps>import-module 
c:\<path>\IntelNetCmdlets\"). In Microsoft Windows* 10 and Windows Server* 
2016, the auto-complete function appends a trailing backslash. If you use 
auto-complete when entering the Import-Module command, delete the trailing 
backslash before pressing Return to execute the command.

Code 10 Error in Device Manager When Intel DCB Installed and RSS Queues
Changed to 16 or Greater
-----------------------------------------------------------------------
If the Intel DCB feature is installed, changing the number of Receive Side 
Scaling (RSS) queues to 16 or greater may result in a Code 10 error in Device 
Manager. To resolve this issue, reinstall the driver from the Intel 
installation media. Note that this will reset the RSS queues value to the 
default of 8. Do not change the RSS queues to 16 or greater, as doing so will 
result in another Code 10 error. Setting RSS queues to a lower value such as 1, 
2, or 4 does not cause error.

"Error getting the adapter info" message when opening device property sheet
---------------------------------------------------------------------------
Earlier versions of Windows Defender may mistake some Intel PROSet DLLs for 
malware and delete these files. This causes an "Error getting the adapter info" 
error. This issue affects Microsoft Windows* 7. Update Windows Defender to the 
latest version and reinstall the Intel PROSet software to resolve the issue.

Driver Installation Issues on Microsoft* Windows* 10
----------------------------------------------------
Release 20.7 (or later) driver installs on Microsoft Windows 10 may time out or 
fail due to extended wait time (up to 4 minutes per Ethernet port). In most 
cases, despite the timeout, the driver installs correctly and is usable. If the 
driver does not install correctly, retry the installation process. Note that 
Intel(R) PROSet for Windows Device Manager relies on correctly installed 
drivers.

Lower than expected throughput on X710/XL710 based devices
----------------------------------------------------------
If you have an X710 or XL710 based device installed in a four CPU socket 
system. Receive and transmit traffic may be significantly lower than expected. 
Setting your interrupt rate to High may mitigate the issue.

Link loss after identifying the adapter
---------------------------------------
All ports on the device may lose link when you run the diagnostic tests to 
identify the adapter on a single port. Link will return to normal after several 
seconds. This only affects 10G-BaseT devices based on the Intel(R) Ethernet 
Controller X710.

System does not get link when connected to a 10GbE switch
---------------------------------------------------------
Systems that contain an Intel(R) i210 or i211 device may not link to a 10GbE 
switch. This may happen when the system's Ethernet cable is not connected to 
the switch during power up or if the cable is disconnected for more than a 
couple of minutes. Disabling and enabling the device in the operating system 
will restore link.

iSCSI traffic stops after disabling RSC
---------------------------------------
To prevent a lost connection, Receive Segment Coalescing (RSC) must be disabled 
prior to configuring a VLAN bound to a port that will be used for connecting to 
an iSCSI target. Workaround this issue by disabling Receive Segment Coalescing 
before setting up the VLAN. This will avoid this traffic stop.

Multicast routing table is not automatically set up
---------------------------------------------------
The multicast routing table for the Intel(R) Ethernet Virtual Function 700 
Series driver is not automatically set up and the virtual machine will not 
receive multicast traffic. Manually adding the multicast routing will resolve 
the issue.

Enable PME setting not set to expected value
--------------------------------------------
After running Sysprep, the Enable PME setting may not be set to the expected 
value. You should manually verify and configure the setting.

Receive Side Scaling value is blank
-----------------------------------
Changing the Receive Side Scaling setting of an adapter in a team may cause the 
value for that setting to appear blank when you next check it. It may also 
appear blank for the other adapters in the team. The adapter may be unbound 
from the team in this situation. Disabling and enabling the team will resolve 
the issue.

CPU utilization higher than expected
------------------------------------
Setting RSS Queues to a value greater than 4 is only advisable for large web 
servers with several processors. Values greater than 4 may increase CPU 
utilization to unacceptable levels and have other negative impacts on system 
performance.

RSS Load Balancing Profile Advanced Setting
-------------------------------------------
Setting the "RSS load balancing profile" Advanced Setting to "ClosestProcessor" 
may significantly reduce CPU utilization. However, in some system 
configurations (such as a system with more Ethernet ports than processor 
cores), the "ClosestProcessor" setting may cause transmit and receive failures. 
Changing the setting to "NUMAScalingStatic" will resolve the issue.

Unexpected link loss when connected to Netgear XSM7224S switch
--------------------------------------------------------------
The Netgear XSM7224s switch is sensitive to Energy Efficient Ethernet (EEE) 
mode. Link flap errors will occur with several Intel devices when EEE mode is 
enabled. Disable EEE mode to resolve the issue. This issue affects devices 
based on the following:
* Intel(R) I350 controller
* Intel(R) 82579 series of controllers
* Intel(R) I217 series of controllers
* Intel(R) I218 series of controllers

Opening Windows Device Manager property sheet takes longer than expected
------------------------------------------------------------------------
The Windows Device Manager property sheet may take 60 seconds or longer to 
open. The driver must discover all Intel Ethernet devices and initialize them 
before it can open the property sheet. This data is cached, so subsequent 
openings of the property sheet are generally quicker.

Audio or video distortion when LAN cable is connected or disconnected
---------------------------------------------------------------------
Momentary audio distortion or video playback issues may occur when you connect 
or disconnect a LAN cable to the onboard Ethernet port. Intel(R) 82577 and 
82578 based network connections are affected by this issue.

Reduced or erratic receive performance
--------------------------------------
Intel(R) 7500 chipset-based systems may experience degraded receive 
performance. Increasing receive descriptors to 1024 will resolve the issue. 
Disabling C-states in the system BIOS will also resolve the issue.

Unexpected NMI with 82599-based NICs
------------------------------------
If you set the PCIe Maximum Payload Size to 256 bytes in your system BIOS and 
install an 82599-based NIC, you may receive an NMI when the NIC attains link. 
This happens when the physical slot does not support a payload size of 256 
Bytes even if the BIOS does. Moving the adapter to a slot that supports 256 
bytes will resolve the issue. Consult your system documentation for information 
on supported payload values.

VLANs are not supported on VMQ enabled adapters and teams
---------------------------------------------------------
If you create a VLAN on a VMQ enabled adapter, the VMQ setting will 
automatically be set to disabled. The same will happen if you create a VLAN on 
a team whose member adapters have VMQ enabled.

Unexpected Connectivity Loss
----------------------------
If you uncheck the "Allow the computer to turn off this device to save power" 
box on the Power Management tab and then put you system to sleep, you may lose 
connectivity when you exit sleep. You must disable and enable the NIC to 
resolve the issue. Installing Intel(R)PROSet for Windows Device Manager will 
also resolve the issue.

SNMP errors in the System Event Log
-----------------------------------
Under Microsoft Windows 7 or Windows Server 2008 R2, you may see the following 
error in the System Event Log: "The SNMP Service encountered an error while 
accessing the registry key 
"SYSTEM\CurrentControlSet\Servcies\SNMP\Parameters\TrapConfiguration"
The Windows 7 SNMP service start up isn't properly configuring the service with 
a TrapConfiguration key. Perform the following to correct the issue:
1. Open Services applet (run services.msc).
2. Right click on SNMP Service, then select Properties.
3. Click on the Traps tab. Enter "public" for the Community name and click Add 
to list.
4. Click on the Security tab. Click the Add button. Enter "public" and click on 
the Add button.

VLANs unsupported on some Intel devices
---------------------------------------
The following devices do not support VLANs:
- Intel(R) 82567V-2 Gigabit Network Connection
- Intel(R) 82567V Gigabit Network Connection

Reduced Large Send Offload performance
--------------------------------------
Large Send Offload (LSO) and IPSec Offload are not compatible. LSO is 
automatically disabled when IPSec Offload is enabled. This may reduce the 
performance of non-IPSec traffic. Confining all of your IPSec traffic to one 
port and enabling IPSec Offload only on that port may mitigate this issue. On 
Microsoft Windows 8.1 and Server 2012 and later, devices based on the 82576, 
82599, and X540 controllers are not affected by this issue.

Procedure for installing and upgrading drivers and utilities
------------------------------------------------------------
Intel does not recommend installing or upgrading drivers and Intel(R) PROSet 
software over a network connection. Instead, install or upgrade drivers and 
utilities from each system. To install or upgrade drivers and utilities, follow 
the instructions in the User Guide.

"Malicious script detected" warning from Norton AntiVirus* during
PROSet Uninstall
-----------------------------------------------------------------
The Intel PROSet uninstall process uses a Visual Basic script as part of the 
process. Norton AntiVirus and other virus scanning software may mistakenly flag 
this as a malicious or dangerous script. Letting the script run allows the 
uninstall process to complete normally.

"Out Of Disk Space" Message during Installation
-----------------------------------------------
The boot partition requires a minimum of 15 MB free space in order to install 
Intel PROSet, regardless of which drive you specify for installation. If there 
is insufficient space on the partition you will see this error message, and the 
product will not install.

Windows Code 10 Error Message on Driver Install or Upgrade
----------------------------------------------------------
If you encounter a Windows Code 10 error message when installing or upgrading 
drivers, reboot to resolve the issue.

No settings available on the Intel(R) Boot Options tab in Windows Device
Manager after flashing an EFI image
------------------------------------------------------------------------
The settings have been hidden because the EFI environment does not make use of 
them.

Network stack will not enable RSC
---------------------------------
If Intel Data Center Bridging (DCB) is installed, the network stack will not 
enable Receive Segment Coalescing (RSC).

PXE option ROM does not follow the PXE specification with respect to the
final "discover" cycle
------------------------------------------------------------------------
In order to avoid long wait periods, the option ROM no longer includes the 
final 32-second discover cycle. (If there was no response in the prior 
16-second cycle, it is almost certain that there will be none in the final, 
32-second cycle.

Customer Support
================

- Main Intel support website: http://support.intel.com
- Network products information:
http://support.intel.com/support/go/network/adapter/home.htm

Legal / Disclaimers
===================

Copyright (C) 2002 - 2020, Intel Corporation. All rights reserved.
Parts of Intel(R) PROSet for Windows Device Manager are based on the pugixml 
library (http://pugixml.org). pugixml is Copyright (C) 2006-2015 Arseny 
Kapoulkine.

Intel Corporation assumes no responsibility for errors or omissions in this 
document. Nor does Intel make any commitment to update the information 
contained herein.

Intel and the Intel logo are trademarks of Intel Corporation or its 
subsidiaries in the U.S. and/or other countries.
Itanium is a trademark or registered trademark of Intel Corporation or its 
subsidiaries in the U.S. and/or other countries.

* Other product and corporate names may be trademarks of other companies and 
are used only for explanation and to the owners' benefit, without intent to 
infringe.

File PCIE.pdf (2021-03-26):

### PCI Express

# PCI Express

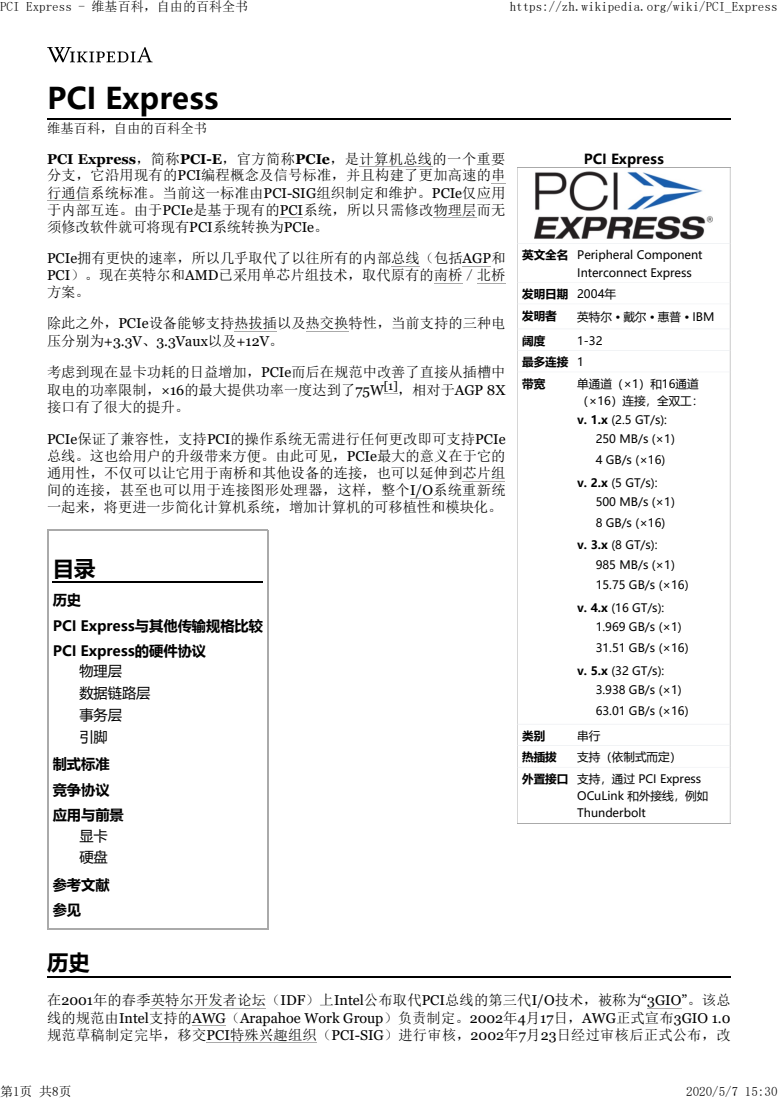
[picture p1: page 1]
Interconnect Express 发明日期 2004年; 发明者; 英特尔 • 戴尔 • 惠普 • IBM; 最多连接 1; 单通道（×1）和16通道; （×16）连接，全双工： v. 1.x (2.5 GT/s): 250 MB/s (×1) 4 GB/s (×16); 热插拔; 支持（依制式而定）; 维基百科，自由的百科全书; 考虑到现在显卡功耗的日益增加，PCIe而后在规范中改善了直接从插槽中 取电的功率限制，×16的最大提供功率一度达到了75W[1]，相对于AGP 8X 接口有了很大的提升。; 历史 PCI Express与其他传输规格比较 PCI Express的硬件协议 物理层 数据链路层 事务层 引脚 制式标准 竞争协议 应用与前景 显卡 硬盘 参考文献 参见; PCI Express - 维基百科，自由的百科全书; https://zh.wikipedia.org/wiki/PCI_Express

PCI Express，简称PCI-E，官方简称PCIe，是计算机总线的一个重要
分支，它沿用现有的PCI编程概念及信号标准，并且构建了更加高速的串
行通信系统标准。当前这一标准由PCI-SIG组织制定和维护。PCIe仅应用
于内部互连。由于PCIe是基于现有的PCI系统，所以只需修改物理层而无
须修改软件就可将现有PCI系统转换为PCIe。 PCIe拥有更快的速率，所以几乎取代了以往所有的内部总线（包括AGP和

英文全名 Peripheral Component

PCI）。现在英特尔和AMD已采用单芯片组技术，取代原有的南桥／北桥

除此之外，PCIe设备能够支持热拔插以及热交换特性，当前支持的三种电
压分别为+3.3V、3.3Vaux以及+12V。

PCIe保证了兼容性，支持PCI的操作系统无需进行任何更改即可支持PCIe
总线。这也给用户的升级带来方便。由此可见，PCIe最大的意义在于它的
通用性，不仅可以让它用于南桥和其他设备的连接，也可以延伸到芯片组
间的连接，甚至也可以用于连接图形处理器，这样，整个I/O系统重新统
一起来，将更进一步简化计算机系统，增加计算机的可移植性和模块化。

外置接口 支持，通过 PCI Express

OCuLink 和外接线，例如
Thunderbolt

在2001年的春季英特尔开发者论坛（IDF）上Intel公布取代PCI总线的第三代I/O技术，被称为“3GIO”。该总
线的规范由Intel支持的AWG（Arapahoe Work Group）负责制定。2002年4月17日，AWG正式宣布3GIO 1.0
规范草稿制定完毕，移交PCI特殊兴趣组织（PCI-SIG）进行审核，2002年7月23日经过审核后正式公布，改

名为“PCI Express”，并根据开发蓝图在2006年正式推出Spec 2.0（2.0规范）。[2][3]2019年5月28日，PCI-SIG官方发布了PCIe 5.0的1.0版基础规范，规范主要定义了PCIe5.0的架构（architecture）、互联属性规范 （interconnect attributes）、网络结构管理（fabric management）以及编程接口（programming interface） 等内容[4]
。 | PCI Express 总线性能[2][3]

PCI
Express
版本
| 推出 | Line
| | 编码 | 原始
| | | 传输率[i] | | | 带宽（带宽）[i]
| | | | ×1 | ×2 | ×4 | ×8 | ×16
1.0 | 2003 | 8b/10b | 2.5 GT/s | 250 MB/s | 0.50 GB/s | 1.0 GB/s | 2.0 GB/s | 4.0 GB/s
2.0 | 2007 | 8b/10b | 5.0 GT/s | 500 MB/s | 1.0 GB/s | 2.0 GB/s | 4.0 GB/s | 8.0 GB/s
3.0 | 2010 | 128b/130b | 8.0 GT/s | 984.6 MB/s | 1.97 GB/s | 3.94 GB/s | 7.88 GB/s | 15.8 GB/s
4.0 | 2017 | 128b/130b | 16.0 GT/s | 1969 MB/s | 3.94 GB/s | 7.88 GB/s | 15.75 GB/s | 31.5 GB/s
5.0[5][6] | 2019[7][8] | NRZ
| | 128b/130b | 32.0 GT/s[ii] | 3938 MB/s | 7.88 GB/s | 15.75 GB/s | 31.51 GB/s | 63.0 GB/s

6.0 2021

| | PAM4 &
| | FEC
| | 128b/130b | 64.0 GT/s | 7877 MB/s | 15.75 GB/s | 31.51 GB/s | 63.02 GB/s | 126.03 GB/s

## i. 每条通道（lane）是全双工通道。 ii. 出于技术可行性，最初也考虑过25.0 GT/s

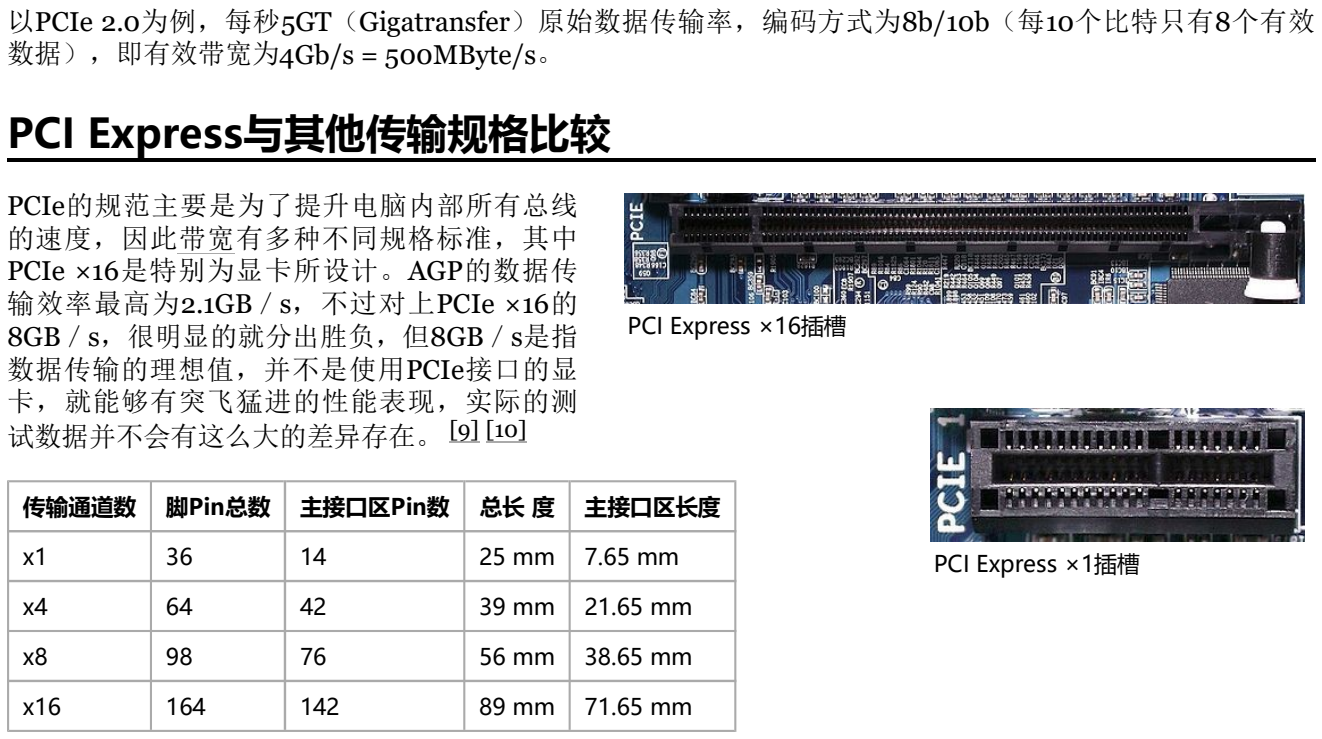
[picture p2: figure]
PCI Express ×16插槽; PCI Express ×1插槽; 以PCIe 2.0为例，每秒5GT（Gigatransfer）原始数据传输率，编码方式为8b/10b（每10个比特只有8个有效 数据），即有效带宽为4Gb/s = 500MByte/s。 PCIe的规范主要是为了提升电脑内部所有总线; 的速度，因此带宽有多种不同规格标准，其中 PCIe ×16是特别为显卡所设计。AGP的数据传 输效率最高为2.1GB／s，不过对上PCIe ×16的 8GB／s，很明显的就分出胜负，但8GB／s是指 数据传输的理想值，并不是使用PCIe接口的显 卡，就能够有突飞猛进的性能表现，实际的测 试数据并不会有这么大的差异存在。 [9] [10]; 传输通道数; 脚Pin总数; 主接口区Pin数; 主接口区长度; PCI Express与其他传输规格比较

第2页 共8页 | 2020/5/7 15:30

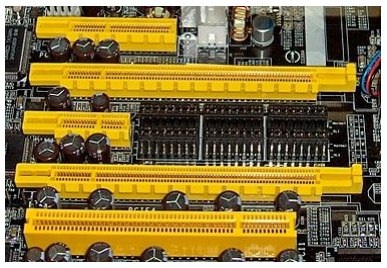
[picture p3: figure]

各式不同的PCI Express插槽（由上而
下：x4, x16, x1，与x16），相较于传统
的32-bit PCI插槽（最下方），取自于DFI
的LanParty nF4 Ultra-D机板
规格 | 总线宽度 | 工作时脉 | 数据速率
PCI 2.3 | 32位 | 33/66 MHz | 133/266 MB/s
PCI-X 1.0 | 64位 | 66/100/133 MHz | 533/800/1066 MB/s
PCI-X 2.0（DDR） | 64位 | 133 MHz | 2.1 GB/s
PCI-X 2.0（QDR） | 64位 | 133 MHz | 4.2 GB/s
AGP 2X | 32位 | 66 MHz | *2=532 MB/s
AGP 4X | 32位 | 66 MHz | *4=1.0 GB/s
AGP 8X | 32位 | 66 MHz | *8=2.1 GB/s
PCI-E 2.0 X1 | 1比特 | 2.5 GHz | 500 MB/s
PCI-E 2.0 X2 | 2比特 | 2.5 GHz | 1 GB/s
PCI-E 2.0 X4 | 4位 | 2.5 GHz | 2 GB/s
PCI-E 2.0 X8 | 8位 | 2.5 GHz | 4 GB/s
PCI-E 2.0 X16 | 16位 | 2.5 GHz | 8 GB/s

计算公式：PCI-E串行总线带宽（MB/s） = 串行总线时钟频率（MHz）* 串行总线位宽（bit/8 = B）* 串行总 线管线* 编码方式* 每时钟传输几组数据（cycle），例：双工PCI-E 1.0 X1，其带宽 = 2500*1/8*1*8 /10*1*2=500 MB/s。 PCI Express 1.0总线 频率2500 MHz，这是在 100 MHz的基准频率通过锁 相环振荡器（Phase Lock

Loop，PLL）达到的。PCI-E 2.0总线频率从2.5GHz提高到5GHz，3.0则提高到8GHz，编码方式变成 128/130。 PCIe的连接是创建在一个单向的序列的（1-bit）点对点连接基础之上，这称之为通道（lane）。这一点上

PCIe连接与早期PCI连接形成鲜明对比，PCI连接基于总线控制，所有设备共享双向32位并行总线。PCIe是一 个多层协议，由事务层，数据交换层和物理层构成。物理层又可进一步分为逻辑子层和电气子层。逻辑子层又 可分为物理代码子层（PCS）和介质接入控制子层（MAC）。这些术语借用自 IEEE 802 网络协议模型。PCIe 通过ASPM协议进行电源管理。

于使用电力方面，每组流水线使用两个单向的低电压差分信号 （LVDS）合计达到2.5 Gbit/s。传送及接收不同数据会使用不同的传 输通道，每一通道可运作四项资料。两个PCIe设备之间的连接成为 “链接”，这形成1组或更多的传输通道。各个设备最少支持1传输通道

（x1）的链接。也可以有2，4，8，16，32个通道的链接。这可以更 好的提供双向兼容性（x2模式将用于内部接口而非插槽模式）。PCIe 卡能使用在至少与之传输通道相当的插槽上（例如x1接口的卡也能工 作在x4或x16的插槽上）。一个支持较多传输通道的插槽可以创建较 少的传输通道（例如8个通道的插槽能支持1个通道）。PCIe设备之间 的链接将使用两设备中较少通道数的作为标准。一个支持较多通道的 设备不能在支持较少通道的插槽上正常工作，例如x4接口的卡不能在 x1的插槽上正常工作（插不入），但它能在x4的插槽上只创建1个传 输通道（x1）。PCIe卡能在同一数据传输通道内传输包括中断在内的 全部控制信息。这也方便与PCI的兼容。多传输通道上的数据传输采 取交叉访问，这意味着连续字节交叉访问在不同的通道上。这一特性 被称之为“数据条纹”，需要非常复杂的硬件支持连续数据的同步访问，也对链接的数据吞吐量要求极高。由于 数据填充的需求，数据交叉访问不需要缩小数据包。与其它高速数传输协议一样，时钟信息必须嵌入信号中。 在物理层上，PCIe采用常见的8B/10B代码方式来确保连续的1和0字符串长度符合标准，这样保证接收端不会

# PCI Express的硬件协议

## 物理层

第3页 共8页 | 2020/5/7 15:30

误读。编码方案用10位编码比特代替8个未编码比特来传输数据，占用20%的总带宽。到了PCIe 3.0，采用 128B/130B代码方式，仅占用1.538%的总带宽。有些协议（如SONET）使用另外的编码结构如“不规则”在数 据流中嵌入时钟信息。PCIe的特性也定义一种“不规则化”的运算方法，但这种方法与SONET完全不同，它的 方法主要用来避免数据传输过程中的数据重复而出现数据散射。第一代PCIe采用2.5GT/s单信号传输率，PCI-SIG计划在未来版本中增强到5~10GT/s。

数据链路层采用按序的交换层信息包（Transaction Layer Packets,TLPs），是由交换层生成，按32位循环冗 余校验码（CRC，本文中用LCRC）进行数据保护，采用著名的协议（Ack and Nak signaling）的信息包。 TLPs能通过LCRC校验和连续性校验的称为Ack（命令正确应答）；没有通过校验的称为Nak（没有应答）。 没有应答的TLPs或者等待超时的TLPs会被重新传输。这些内容存储在数据链路层的缓存内。这样可以确保 TLPs的传输不受电子噪音干扰。PCIe对于ACK有所规范，在收到TLP数据包之后，在一定时间内必须回应 ACK，也就是ACK延迟（ACK Latency）的等待时间。因应ACK/NAK流程的需要，必须实现出重新播送缓冲 器（Replay Buffer）。

TLPs加上Sequence number以及16 比特 CRC 后，被包裹成为数据链路层信息包（Data Link Layer Packet,DLLP），除了数据传递外，交握信号ACK和NAK信号亦被包裹在信息包中发送，除此之外也用来传送 两个互连设备的交换层之间的流控制信息和实现电源管理功能。

PCI Express采用分离交换（数据提交和应答在时间上分离），可保证传输通道在目标端设备等待发送回应信 息传送其它数据信息。

PCI Express采用可信性流控制。这一模式下，一个设备广播它可接收缓存的初始可信信号量。链接另一方的 设备会在发送数据时统计每一发送的TLP所占用的可信信号量，直至达到接收端初始可信信号最高值。接收端 在处理完毕缓存中的TLP后，它会回送发送端一个比初始值更大的可信信号量。可信信号统计是定制的标准计 数器，相比于其他方法，如基于握手的传输协议，这一模式的优势在于可信信号的回传反应时间不会影响系统 性能，因为如果双方设备的缓存足够大，是不会出现达到可信信号最高值的情况，这样发送数据不会停顿。

第一代PCIe标称可支持每传输通道单向每秒250 MB的数据传输率。这一数字是根据物理信号率2500 Mbit/s 除以编码率（10位／每字节）计算而得。这意味着一个16通道（x16）的PCIe卡理论上可以达到单向 250*16=4000 MB/s（3.7 GB/s）。实际的传输率要根据数据有效载荷率，即依赖于数据的本身特性，这是由 更高层（软件）应用程序和中间协议层决定。

PCI Express与其它高速序列连接系统相似，它依赖于传输的鲁棒性（CRC校验和ACK）。长时间连续的单向 数据传输（如高速存储设备）可以达到>95%的PCIe通道数据传输利用率。这样的传输受益于增加的传输通道 （x2, x4 等）。但大多数应用程序如USB或以太网控制器会把传输内容拆成小的数据包，同时还会强制加上确 认信号。这类数据传输由于增加数据包的解析和强制中断，降低传输通道的效率。作为一个在同一个印刷电路 板（PCB）设备间的通信协议，它不需要达到其他远距离通信协议要求的高数据传输错误容忍度，而且，这种 效率的降低并非只出现在PCIe上。

下表列出在边缘连接器上的PCI Express卡两侧的导线。在印刷电路板（PCB）的焊接侧为A侧，并且组件侧的 B侧。[11]PRSNT1# 和PRSNT2# 引脚必须比其余稍短，以确保热插入卡完全插入。该WAKE# 引脚采用全电 压唤醒计算机，但必须拉高从备用电源，以表明该卡是能够唤醒。[12]

## 数据链路层

## 事务层

引脚

第4页 共8页 | 2020/5/7 15:30

PCI Express连接器引脚（×1，×4，×8，×16的变体） 引
脚
B侧 | A侧 | 描述 | 引 脚 | B侧 | A侧 | 描述
1 | +12 V | PRSNT1# | 必须连接到最远PRSNT2# 引 脚
| | | − 4
| | | 50 | HSOp (8) | Reserved | 通道8传输数据，+和
| | | | | | −
2 | +12 V | +12 V | 51 | HSOn (8) | Ground
3 | +12 V | +12 V | 52 | Ground | HSIp (8) | 通道8接收数据，+和
Ground | Ground | 53 | Ground | HSIn (8)
5 | SMCLK | TCK

SMBus和JTAG端口引脚

54 | HSOp (9) | Ground | 通道9传输数据，+和
− 6 | SMDAT | TDI | 55 | HSOn (9) | Ground
7 | Ground | TDO | 56 | Ground | HSIp (9) | 通道9接收数据，+和
− 8 | +3.3 V | TMS | 57 | Ground | HSIn (9)
9 | TRST# | +3.3 V | 58 | HSOp
(10) Ground
通道10传输数据，+和
−
10 +3.3 V
aux | +3.3 V | 备用电源 | 59 | HSOn
(10) Ground
11 | WAKE# | PERST# | 链接激活；基本复位 | 60 | Ground | HSIp
(10) 通道10接收数据，+和
−
Key notch | 61 | Ground | HSIn (10)
12 | CLKREQ# | Ground | 要求运行的时钟 | 62 | HSOp
(11) Ground
通道11传输数据，+和
−
13 | Ground | REFCLK+ | 参考时钟差分对 | 63 | HSOn
(11) Ground
14 | HSOp (0) | REFCLK− | 通道0传输数据，+和−
64 | Ground | HSIp
(11) 通道11接收数据，+和
−
15 | HSOn (0) | Ground | 65 | Ground | HSIn (11)
16 | Ground | HSIp (0)
通道0接收数据，+和− | 66 HSOp | (12) Ground
| | (12) Ground

通道12传输数据，+和
−
17 | PRSNT2# | HSIn (0) | 67 | HSOn
18 | Ground | Ground | 68 | Ground | HSIp
(12) 通道12接收数据，+和
−
PCI Express ×1卡于引脚18结束 | 69 | Ground | HSIn (12)
19 | HSOp (1) | Reserved
通道1传输数据，+和− | 70 HSOp | (13) Ground
| | (13) Ground
| 72 | Ground | HSIp

通道13传输数据，+和
−
20 | HSOn (1) | Ground | 71 | HSOn
21 | Ground | HSIp (1) | 通道1接收数据，+和−
(13) 通道13接收数据，+和
−
22 | Ground | HSIn (1) | 73 | Ground | HSIn (13)
23 | HSOp (2) | Ground
通道2传输数据，+和− | 74 HSOp | (14) Ground
| | (14) Ground

通道14传输数据，+和
−
24 | HSOn (2) | Ground | 75 | HSOn
第5页 共8页 | 2020/5/7 15:30

25 | Ground | HSIp (2)
通道2接收数据，+和−
| | | 76 | Ground | HSIp
(14) 通道14接收数据，+和
−
26 | Ground | HSIn (2) | 77 | Ground | HSIn (14)
27 | HSOp (3) | Ground
通道3传输数据，+和−

### 78 HSOp

(15) Ground
通道15传输数据，+和
−
28 | HSOn (3) | Ground | 79 | HSOn
| (15) Ground
80 | Ground | HSIp
29 | Ground | HSIp (3) | 通道3接收数据，+和−
(15) 通道15接收数据，+和
−
30 | Reserved | HSIn (3) | 81 | PRSNT2# | HSIn (15)
31 | PRSNT2# | Ground | 82 | Reserved | Ground
32 | Ground | Reserved
PCI Express ×4卡于引脚32结束
33 | HSOp (4) | Reserved | 通道4传输数据，+和−
34 | HSOn (4) | Ground
35 | Ground | HSIp (4)
通道4接收数据，+和−
36 | Ground | HSIn (4)
37 | HSOp (5) | Ground | 通道5传输数据，+和−
38 | HSOn (5) | Ground
39 | Ground | HSIp (5) | 通道5接收数据，+和−
40 | Ground | HSIn (5)
41 | HSOp (6) | Ground | 通道6传输数据，+和−
42 | HSOn (6) | Ground
43 | Ground | HSIp (6)
通道6接收数据，+和−
| | | | | 图例
44 | Ground | HSIn (6) | | 接地引脚 | 零电压基准
45 | HSOp (7) | Ground | 通道7传输数据，+和−
| | | | 电源引脚 | 为PCIe卡供电
46 | HSOn (7) | Ground | | 输出引脚 | 从PCIe卡到主板的信号
47 | Ground | HSIp (7) | 通道7接收数据，+和−
| | | | 输入引脚 | 从主板到PCIe卡的信号
48 | PRSNT2# | HSIn (7) | | 漏极开路 | 可拉至低电平或感应到多个卡
49 | Ground | Ground | | 检测引脚 | 卡连接在一起
PCI Express ×8卡于引脚49结束 | 备用 | 当前没有使用，不连接

半高卡 Mini PCIe：用以代替Mini PCI卡（支持x1 PCIe、USB 2.0和SMBus总线接口）。 ExpressCard：类似PC卡接口标准（支持x1 PCIe、USB 2.0/3.0、热插拔）。 PCI Express ExpressModule：支持热插拔的接口标准，用于服务器和工作站上。 XMC：类似CMC／PMC接口标准（支持x4 PCIe或串行RapidI/O）。 AdvancedTCA：用以代替Compact PCI卡，支持串行背板拓扑结构基础。 AMC：AdvancedTCA规范的补充，支持处理器和I/O模块在ATCA板上（x1、x2、x4或x8 PCIe）。 PCI Express外置接线[13]。

# 制式标准

第6页 共8页 | 2020/5/7 15:30

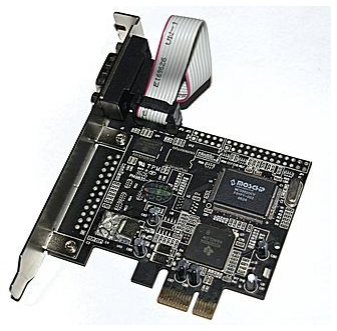
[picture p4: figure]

有RS-232接口的PCIe x1卡

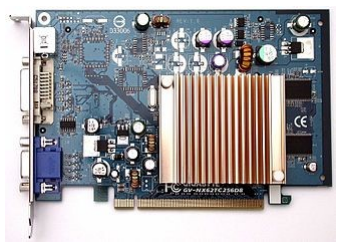
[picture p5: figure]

技嘉GV-NX62TC256D8显卡，采用
PCI Express x16插槽

## Mobile PCI Express Module（MXM）英伟达所发明的图形模块规

范。

## Advanced eXpress I/O Module（AXIOM）图形模块，由ATI认可。 Thunderbolt

M.2
U.2

基 于 高 速 序 列 构 架 产 生 了 很 多 传 输 标 准 ， 包 括 HyperTransport 、 InfiniBand、RapidIO和StarFabric等等。这些标准均有业界的不同企业

支持，背后也都有大量的资金投入标准的研究开发，所以每一标准都声称 自己与众不同，独占优势。主要的差异在于可扩展性、灵活性与反应时 间、单位成本的取舍平衡各不相同。其中的一个例子是在传输包上增加一个复杂的头信息以支持复杂路由传输 （PCI Express不支持这种方式）。这样的信息增加降低了接口的有效带宽也使传输更复杂，但是相应创造了 新的软件支持此功能。这种架构下需要软件追踪网络拓扑结构的变化以实现系统支持热插拔。InfiniBand和 StarFabric标准即能实现这一功能。另一个例子是缩小信息包以减少反应时间。较小的信息包意味着包头占用 了包的更大百分比，这样又降低了有效带宽。能实现此功能的标准是RapidIO和HyperTransport。PCI Express取中庸之道，定位于设计成一种系统互连接口而非一种设备接口或路由网络协议。另外为了针对软件 透明，它的设计目标限制了它作为协议，也在某种程度上增加了它的反应时间。

在2005年，PCIe已近乎成为新的个人电脑主板标准。关于此有不少评 论，但最基本的原因是它对于软件开发者完全透明——为PCI所设计的操 作系统可以不做任何代码修改来启动PCIe设备。其二，它能增强系统性 能，还有强有力的品牌认知。各类网卡、声卡、显卡，以及当下的NVMe 固态硬盘都使用了PCIe标准。下面为主流的使用PCIe 的外设产品。

大部分新型的AMD或NVIDIA显卡都使用PCIe标准。NVIDIA在它新开发 的SLI上采用PCIe的高速数据传输，这使得两块相同芯片组显卡可同时工 作于一台电脑之上。AMD公司也基于PCIe开发一种两个GPU一同运作的 技术，称为CrossFire。

当下主流的固态硬盘接口有M.2、U.2、PCIe、SATA、SATA Express、SAS等。M.2和U.2可选PCIe接口[14] 。 NVMe协议是当前最高效的PCIe SSD协议标准。

1. Desktop Boards—Some PCI Express* Graphics cards require extra power. 03-JunE-2004.

## “25W-75W graphics cards are powered through the desktop board's PCI Express x16 connector”

2. PCI Express 4.0 Frequently Asked Questions. pcisig.com. PCI-SIG. [2014-05-18].
3. PCI Express 3.0 Frequently Asked Questions. pcisig.com. PCI-SIG. [2014-05-01].
4. PCI-SIG官网通信接口规范.

## 5. PCIe 4.0 Heads to Fab, 5.0 to Lab. EE Times. 2016-06-26 [2016-08-27]. （原始内容存档于

2016-08-28）.
6. Archived copy. [2016-08-18]. （原始内容存档于2016-08-19）.

# 竞争协议

# 应用与前景

显卡

硬盘

# 参考文献

第7页 共8页 | 2020/5/7 15:30

## 7. https://www.tomshardware.com/news/pci-sig-releases-final-pcie-5-spec,39521.html

8. Doubling Bandwidth in Under Two Years: PCI Express® Base Specification Revision 5.0, Version 0.9 is Now Available to Members. pcisig.com. [2018-12-12] （英语）. 9. Mechanical Drawing for PCI Express Connector. [2007-12-07]. （原始内容存档于2007-12-08）.
10. FCi schematic for PCIe connectors (PDF). [2007-12-07].
11. What is the A side, B side configuration of PCI cards. Frequently Asked Questions. Adex Electronics. 1998 [Oct 24, 2011]. （原始内容存档于2011-11-02）.

## 12. PCI Express Card Electromechanical Specification Revision 2.0

13. PCI Express External Cabling 1.0 Specification. [2007-02-09].
14. https://www.dell.com/support/article/us/en/04/sln301626/how-to-distinguish-the-differences-

## between-m2-cards?lang=en

## PCI PCI-X

M.2

## USB Type-C Express Card USB 3.1

取自“https://zh.wikipedia.org/w/index.php?title=PCI_Express&oldid=59449381”

本页面最后修订于2020年5月1日 (星期五) 08:36。
本站的全部文字在知识共享 署名-相同方式共享 3.0协议之条款下提供，附加条款亦可能应用。（请参阅使用条款） Wikipedia®和维基百科标志是维基媒体基金会的注册商标；维基™是维基媒体基金会的商标。 维基媒体基金会是按美国国内税收法501(c)(3)登记的非营利慈善机构。

参见

第8页 共8页 | 2020/5/7 15:30

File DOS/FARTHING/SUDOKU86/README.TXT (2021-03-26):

       Sudoku86 - a 16-bit Sudoku game for DOS and 8086/8088 CPUs
                    http://sudoku86.sourceforge.net

*** INTRO ***

Sudoku86 is a Sudoku game designed to run under DOS. It is a 16-bit, real
mode application using CGA or VGA video output (320x200). It has been
compiled using Turbo C 2.0.1. Sudoku86 comes with 100 embedded sudoku grids
of variable difficulty, and allows to load external level files, too.

Sudoku86 requires:
 - 50K of free conventional memory
 - an 8086/8088 compatible CPU
 - a CGA, MCGA or VGA graphic card
 - a two-button mouse
 - a DOS 3.0+ compatible operating system

*** USAGE ***

Mouse left click:
 Selects a number when clicked on the left selection panel, and fills a field
 with the selected number when clicked on a playable field.

Mouse right click:
 If clicked on an empty playable field, it will write a 'note' on the field
 with the currently selected digit. If the field already contains this note,
 then the field will get cleared. When clicked on a filled field, right click
 will clear the field, and restore notes that were previously set (if any).

Keyboard:
 1-9   Selects a digit on the left panel
 SPACE Selects the next digit on left panel
 C     Clears the play field
 N     Loads a new level
 F1    Help screen
 F5    Save your game
 F7    Load your game
 ESC   Quits the game

*** CUSTOM LEVELS ***

If you'd like to play your own, custom levels with Sudoku86, then you can use
the included SDM2LEV tool to convert a *.sdm collection of levels into
Sudoku86 native 'LEV' format.

 Example: SDM2LEV levels.sdm levels.lev

*** LICENSE ***

Copyright (C) 2014-2015, Mateusz Viste
All rights reserved.

Redistribution and use in source and binary forms, with or without
modification, are permitted provided that the following conditions are met:

1. Redistributions of source code must retain the above copyright notice,
   this list of conditions and the following disclaimer.

2. Redistributions in binary form must reproduce the above copyright notice,
   this list of conditions and the following disclaimer in the documentation
   and/or other materials provided with the distribution.

THIS SOFTWARE IS PROVIDED BY THE COPYRIGHT HOLDERS AND CONTRIBUTORS "AS IS"
AND ANY EXPRESS OR IMPLIED WARRANTIES, INCLUDING, BUT NOT LIMITED TO, THE
IMPLIED WARRANTIES OF MERCHANTABILITY AND FITNESS FOR A PARTICULAR PURPOSE
ARE DISCLAIMED. IN NO EVENT SHALL THE COPYRIGHT HOLDER OR CONTRIBUTORS BE
LIABLE FOR ANY DIRECT, INDIRECT, INCIDENTAL, SPECIAL, EXEMPLARY, OR
CONSEQUENTIAL DAMAGES (INCLUDING, BUT NOT LIMITED TO, PROCUREMENT OF
SUBSTITUTE GOODS OR SERVICES; LOSS OF USE, DATA, OR PROFITS; OR BUSINESS
INTERRUPTION) HOWEVER CAUSED AND ON ANY THEORY OF LIABILITY, WHETHER IN
CONTRACT, STRICT LIABILITY, OR TORT (INCLUDING NEGLIGENCE OR OTHERWISE)
ARISING IN ANY WAY OUT OF THE USE OF THIS SOFTWARE, EVEN IF ADVISED OF THE
POSSIBILITY OF SUCH DAMAGE.

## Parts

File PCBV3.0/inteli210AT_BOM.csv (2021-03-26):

Comment | Description | Designator | Footprint | LibRef | Pins | Quantity | PartNumber | url
100nF | desc | C13,C12,C11,C10,C9,C8,C7,C6,C5,C4,C3,C2,C1, | C_0603_1608Metric | libref | 2 | 13
39nF | desc | C14, | C_0603_1608Metric | libref | 2 | 1
27pF | desc | C16,C15, | C_0603_1608Metric | libref | 2 | 2
15uF | desc | C18,C17, | C_0603_1608Metric | libref | 2 | 2
3.3k | desc | R1, | R_0603_1608Metric | libref | 2 | 1
NULL | desc | R14,R13,R11,R10, | R_0603_1608Metric | libref | 2 | 4
3.3K | desc | R16,R15,R5, | R_0603_1608Metric | libref | 2 | 3
10k | desc | R17,R12,R7,R6,R4,R3, | R_0603_1608Metric | libref | 2 | 6
4.99k 1% | desc | R18, | R_0603_1608Metric | libref | 2 | 1
160R | desc | R22,R21,R20,R19, | R_0603_1608Metric | libref | 2 | 4
10K | desc | R9,R8,R2, | R_0603_1608Metric | libref | 2 | 3
i210 | desc | U2, | QFN50P900X900X100-65N | libref | 65 | 1
W25Q16 | desc | U3, | SOIC-8_5.23x5.23mm_P1.27mm | libref | 8 | 1
Through Hole Items
PCI-baffle | desc | H1, | i210-pcibaffle | libref | 2 | 1
HR911130C | desc | J1, | HANRUN_HR911130C | libref | 18 | 1
PCIe-x1 | desc | J2, | BUS_PCIexpress_x1 | libref | 36 | 1
25MHz | desc | Y1, | Crystal_HC49-4H_Vertical | libref | 2 | 1

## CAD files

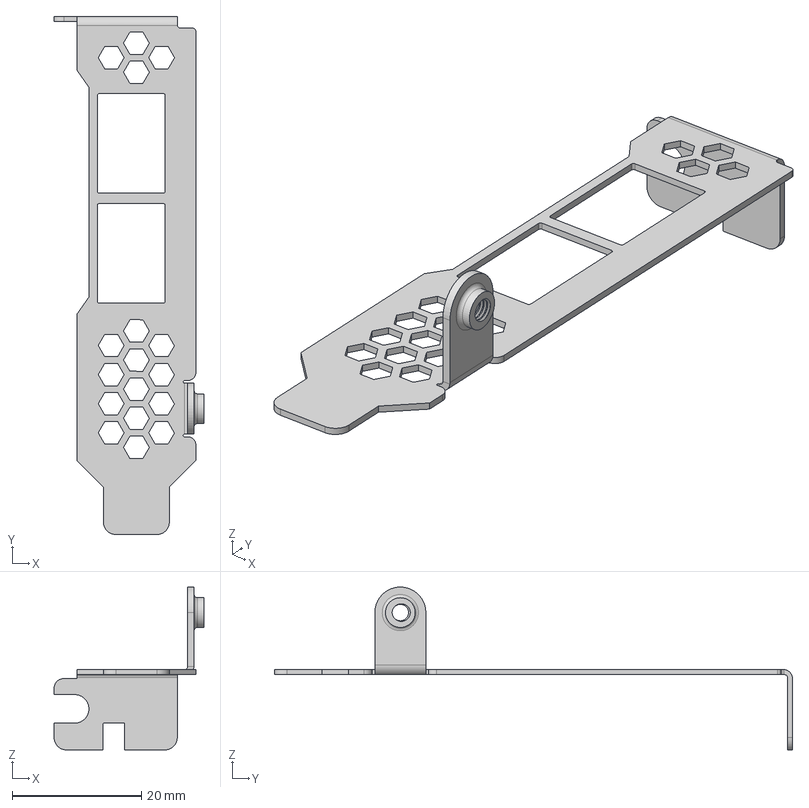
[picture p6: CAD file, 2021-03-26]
PCBV3.0/reference/OCP2PCIe-master/3D_model/半高挡板 (镂空).step
23.2 x 80.1 x 25.2 mm

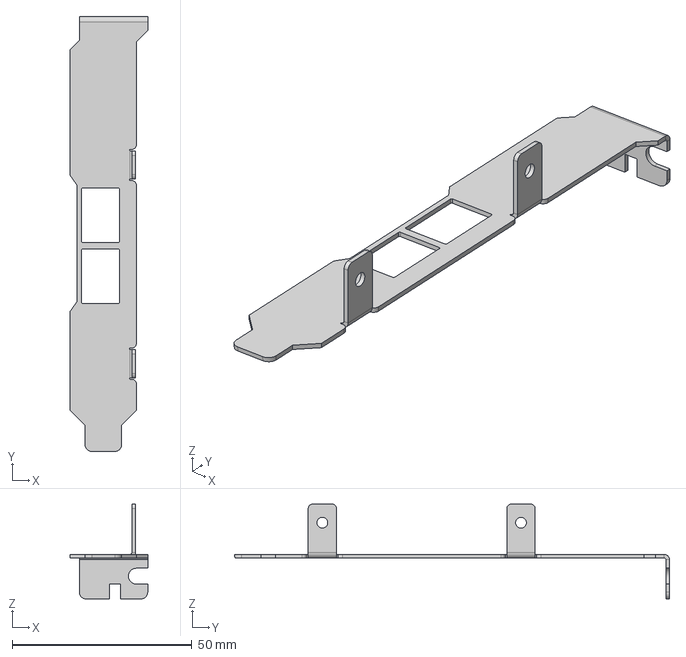
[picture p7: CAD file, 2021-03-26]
PCBV3.0/reference/OCP2PCIe-master/3D_model/挡板V3.2(合适钣金件).step
21.6 x 121.1 x 26.4 mm

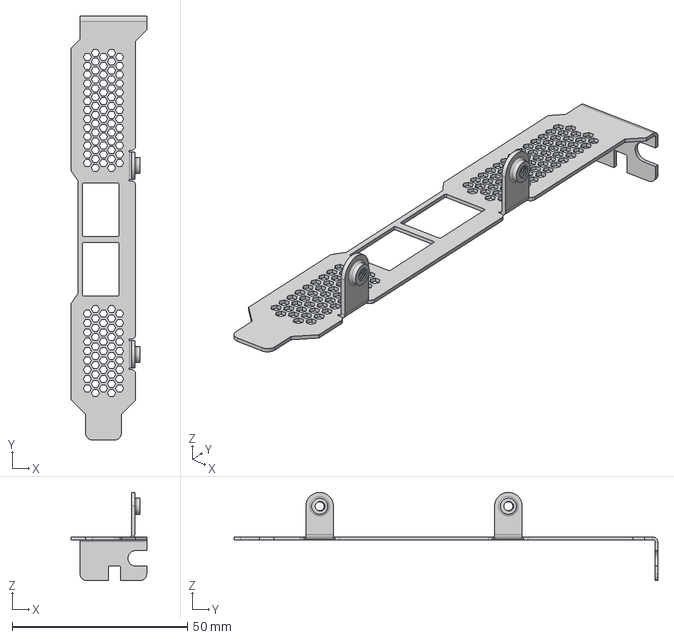
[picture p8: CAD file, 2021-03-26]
PCBV3.0/reference/OCP2PCIe-master/3D_model/全高挡板V4(镂空).step
21.6 x 121.1 x 25.2 mm

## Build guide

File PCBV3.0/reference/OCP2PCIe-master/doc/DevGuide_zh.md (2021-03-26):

# OCP2PCIe
 OCP 夹层网卡转标准 PCIe 槽转接卡设计  
 OCP Mezzanine card V2.0 to standard PCIe slot adapter design
 
 请使用最新版 KiCAD 编辑  
 Please use the latest KiCAD version
 
 KCORES HomeLab 交流群 826702309

# Catalog
**目录**
- **Directory Description**  
 **文件说明**   
 
  - Name Rule  
   项目命名规则  
 
- **Manufacturing instructions**  
**制造说明**

- **Some Problem**  
**疑难问题**

  - About PCIe Lanes Sequence  
   关于 PCIe 通道顺序问题
   
  - ⚠About 5V Power⚠  
   关于5V供电

# Directory Description
**文件说明**  

`\OCP2PCIe_Lib`  
OCP2PCIe 公共 KiCAD 库  
OCP2PCIe public KiCAD lib

`\OCP2PCIe-*-*-*`  
项目分类，命名规则见下一节  
Project classification, see the next section

## Name Rule
 **项目命名规则**  
 
 `OCP2PCIe-H-F-4-V0.1`  @
 
 - OCP2PCIe 项目名称 / Project Name  
 
 - H: 全高 PCI 卡 / Standard Height PCI Card  
 L: 半高 PCI 卡 / Low-Profile PCI Card
 
 - F: PCIe 通道顺序连接 / PCIe lane sequential connection  
 R: PCIe 通道逆序连接 / PCIe lane reverse connection  
 详细描述见最后一节 / See the last paragraph for a detailed explanation
 
 - 1/2/4/8/16: PCIe 通道数 / PCIe Lanes  
 
 - V0.1: 版本号 / Version
 
# Manufacturing instructions
**制造说明**

undone

# Some Problem 
**疑难问题**

## About PCIe Lanes Sequence
**关于 PCIe 通道顺序问题**

OCP卡有两种不同的连接方式，目前已知这两种方式都可以工作，但具体的性能和稳定性影响未知  
OCP Mezz has two different connection methods. Currently it is known that both methods can work, but the specific performance and stability impact is unknown.

- 顺序连接 / Sequential connection  
OCP插槽通道与PCIe通道按顺序相连，如0-0、1-1、2-2、3-3  
The OCP slot lanes are sequentially connected to the PCIe lanes, etc: 0-0, 1-1, 2-2, 3-3  

- 逆序连接 / Reverse link  
OCP插槽通道与PCIe通道按逆序相连，如7-0、6-1、5-2、4-3  
The OCP slot lanes are sequentially connected to the PCIe lanes, etc: 7-0, 6-1, 5-2, 4-3

## About 5V Power
**关于5V供电**

OCP规范需要5V辅助供电，目前已知情况如下：  
 The OCP specification requires a 5V auxiliary power supply. The current known situation is as follows:  

- 不需要5V  
 Don't need 5V
    - intel X540

- 需要5V，但5V电路元器件与12V一致，可以直接与12V连接  
 5V is required, but the 5V circuit components are consistent with 12V and can be directly connected to 12V
    - Mellanox MCX341A  
    - Mellanox MCX342A

- 必须提供稳定的5V供电  
 Must provide stable 5V power
    - 未知 / Uknown

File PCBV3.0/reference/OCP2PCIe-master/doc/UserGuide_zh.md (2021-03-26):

# 快速制作自己的OCP转接卡
by KCORES@awpak78

1. 从[发行页面](https://github.com/KCORES/OCP2PCIe/releases)下载已生成的 Gerber 文件包，这是 PCB 生产通用的工程文件。  
如果你希望为 PCB 添加个性图形或微调尺寸，请下载 KiCAD 工程文件进行修改后自行导出 Gerber。  
**请不要删除作者署名及 Open-Source Hardware 和 GNU GPL 标志**

2. 将 Gerber 文件包上传给 PCB 工厂打样  
 一些 PCB 打样的技术指标
    - 层数：2层
    - 板厚：1.6mm——PCIe卡标准
    - 绝缘漆颜色：随你兴趣——不影响性能
    - 喷镀工艺：喷锡与沉金皆可
        - 喷锡工艺不影响性能，但耐用性较差
        - 沉金价格高昂，多个朋友一起制作才能降低成本
    - 铜厚：1盎司

3. 零件准备
    - OCP 插座推荐使用 FCI 61082-12**2**400 —— 加粗的 **2** 是插座的高度代号  
    或 FCI 61082-12**3**400 这款插座更高，可能会占用下一条 PCI 插槽  
    还有一种方案是 61082-12**1**400 + PCB 垫高板，由于这款插座有廉价的国产替代品，因此备受淘宝JS喜爱
    - M3铜柱 母头对母头，根据不用的插座高度选择
        - FCI 61082-122400 —— 12mm
        - FCI 61082-123400 —— 16mm
        - 61082-121400 + PCB 垫高 —— 未知
    - M3螺丝 8粒

4. 焊接与安装
    - 焊接是最难的一步，有热风枪事半功倍，调温电烙铁也可以接受
    - **请务必单独购买焊锡丝，所有电烙铁附赠的焊锡都是垃圾**
    - 除了建议大家多看点拖焊教程，我也没有办法提供其它的建议，毕竟我就是菜鸡

5. **MCX341用户一定要焊接背面的TP1焊点，为5V引脚通入12V供电**

5. **⚠在上机之前，必须测试引脚之间是否短路**

5. 享受万兆内网吧

# MCX341A改双网口教程

[家用万兆网络指南 6 - 比网线还便宜的双口万兆网卡. 如何给Mellanox网卡刷固件或备份固件](https://zhuanlan.zhihu.com/p/114822136)  
by Karminski-牙医

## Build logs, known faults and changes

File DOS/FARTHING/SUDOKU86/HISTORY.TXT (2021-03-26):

 [ History of Sudoku86 ]

Sudoku86 1.0.3 [23 May 2015]:
 - Video optimizations for faster rendering (10x speedup - the game loads in
   5s on my 8086 PC now instead of 55s in v1.0.2).

Sudoku86 1.0.2 [05 Jul 2014]:
 - Support for double buffering on CGA,
 - A few micro-optimizations of video routines,
 - Fix for mice that return fake release clicks during an onclick event,
 - Added a help screen under F1,
 - Implemented a save/load feature,
 - Added keyboard controls: new game (n), clear game (c), quick selection of
   digits (1-9), next digit (space), help (F1), save (F5) and load (F7),
 - Replaced time() with a call to int21,2Ch (smaller code size),
 - Custom level files support on command line.

Sudoku86 1.0.1 [28 Jun 2014]:
 - Added support for CGA output,
 - Included the SDM2LEV tool into the public package,
 - Makefile and small adaptations for OpenWatcom compilation (courtesy of
   Matej Horvat).

Sudoku86 1.0 [26 Jun 2014]:
 - First public release.

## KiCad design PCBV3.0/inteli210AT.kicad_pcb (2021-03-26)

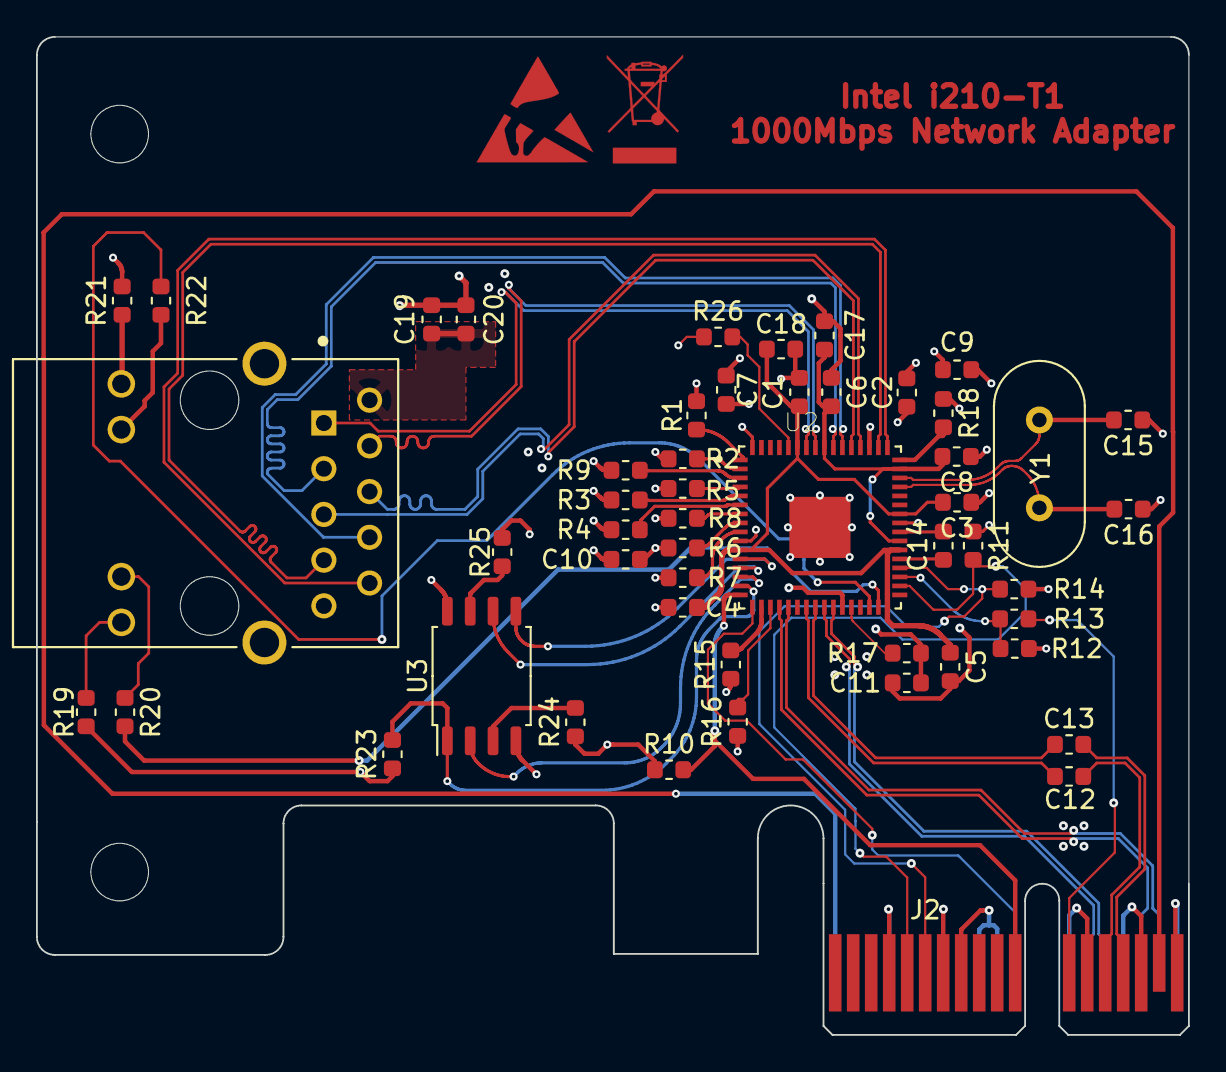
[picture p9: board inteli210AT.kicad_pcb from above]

Board: 4 copper layers, 64.0 x 55.4 mm, 56 parts (0 on the bottom side), 58 nets.

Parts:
C1, C2, C3, C4, C5, C6, C7, C8, C9, C10, C11, C12, C13, C19, C20: 100nF; C_0603_1608Metric
C14: 39nF; C_0603_1608Metric
C15, C16: 27pF; C_0603_1608Metric
C17, C18: 15uF; C_0603_1608Metric
H1: PCI-baffle; i210-pcibaffle
J1: HR911130C; HANRUN_HR911130C
J2: PCIe-x1; BUS_PCIexpress_x1
Logo1, Logo1#2: Logo; WEEE-Logo_4.2x6mm_SilkScreen
Logo2, Logo2#2: Logo; ESD-Logo_6.6x6mm_SilkScreen
R1: 3.3k; R_0603_1608Metric
R2, R8, R9: 10K; R_0603_1608Metric
R3, R4, R6, R7, R12, R17, R26: 10k; R_0603_1608Metric
R5, R15, R16: 3.3K; R_0603_1608Metric
R10, R11, R13, R14: NULL; R_0603_1608Metric
R18: 4.99k 1%; R_0603_1608Metric
R19, R20, R21, R22: 160R; R_0603_1608Metric
R23, R24, R25: 5k; R_0603_1608Metric
U2: i210; QFN50P900X900X100-65N
U3: W25Q16; SOIC-8_5.23x5.23mm_P1.27mm
Y1: 25MHz; Crystal_HC49-4H_Vertical

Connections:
+3V3: C2.2, C7.2, C9.2, C10.2, C11.2, J2.A9, J2.A10, J2.B8, R1.1, R3.1, R4.1, R5.1, R6.1, R7.1, R10.1, R11.1, R12.1, R14.1, R15.1, R16.1, R17.1, R19.2, R21.2, R23.1, R24.1, R25.1, U2.10, U2.27, U2.41, U2.51, U2.64, U3.8
/0V9: C1.2, C3.2, C4.2, C5.2, C18.2, U2.11, U2.32, U2.38, U2.42, U2.59
/1V5: C6.2, C8.2, C17.2, U2.39, U2.47, U2.56
/CLKREQ#: J2.B12, R13.1
/DEV_OFF_N: R17.2, U2.28
/JTAG_CLK: R16.2, U2.19
/JTAG_TDO: R5.2, U2.4
/JTAG_TMS: R15.2, U2.18
/LAN_PWR_GOOD: R1.2, U2.1
/LED0: R20.2, U2.31
/LED1: R22.2, U2.30
/MDI0+: J1.2, U2.58
/MDI0-: J1.3, U2.57
/MDI1+: J1.4, U2.55
/MDI1-: J1.7, U2.54
/MDI2+: J1.5, U2.53
/MDI2-: J1.6, U2.52
/MDI3+: J1.8, U2.50
/MDI3-: J1.9, U2.49
/NC_SI_CLK_IN: R2.2, U2.2
/NC_SI_CRS_DV: R9.2, U2.3
/NC_SI_RXD0: R4.2, U2.6
/NC_SI_RXD1: R3.2, U2.5
/NC_SI_TXD0: R7.2, U2.9
/NC_SI_TXD1: R6.2, U2.8
/NC_SI_TX_EN: R8.2, U2.7
/NVM_CS_N: R23.2, U2.15, U3.1
/NVM_SI: U2.12, U3.5
/NVM_SK: U2.13, U3.6
/NVM_SO: U2.14, U3.2
/PECLK+: J2.A14, U2.26
/PECLK-: J2.A13, U2.25
/PERST#: J2.A11, U2.17
/PE_R+: J2.A17, U2.21
/PE_R-: J2.A16, U2.20
/PE_T+: C12.2, J2.B14
/PE_T-: C13.2, J2.B15
/PE_T_N: C12.1, U2.23
/PE_T_P: C13.1, U2.24
/PRSNT1#: J2.A1, J2.B17
/SMB+: J2.B6, R14.2, U2.36
/SMB-: J2.B5, R11.2, U2.34
/SMB_ALRT_N: R12.2, R13.2, U2.35
/WAKE#: J2.B11, R10.2, U2.16
/XTAL+: C15.2, U2.46, Y1.1
/XTAL-: C16.2, U2.45, Y1.2
GND: C1.1, C2.1, C3.1, C4.1, C5.1, C6.1, C7.1, C8.1, C9.1, C10.1, C11.1, C15.1, C16.1, C17.1, C18.1, C19.1, C20.1, J1.10, J1.15, J1.16, J2.A4, J2.A12, J2.A15, J2.A18, J2.B4, J2.B7, J2.B13, J2.B16, J2.B18, R2.1, R8.1, R9.1, R18.1, R26.1, U2.65, U3.4
unnamed: C14.1, U2.37
unnamed: C14.2, U2.40
unnamed: C19.2, C20.2, J1.1
unnamed: J1.11, R21.1
unnamed: J1.12, R22.1
unnamed: J1.13, R20.1
unnamed: J1.14, R19.1
unnamed: R18.2, U2.48
unnamed: R24.2, U3.3
unnamed: R25.2, U3.7
unnamed: R26.2, U2.60

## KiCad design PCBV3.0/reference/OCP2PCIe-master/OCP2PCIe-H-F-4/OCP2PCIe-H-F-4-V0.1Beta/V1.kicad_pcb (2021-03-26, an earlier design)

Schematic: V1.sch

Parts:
C1: C; CP_Elec_6.3x5.4
C2: C; CP_EIA-7343-31_Kemet-D
C3, C4: C; C_1206_3216Metric
J1: PCI Express x4; BUS_PCIexpress_x4
J2: Conn_02x40_Top_Bottom; FCI_61082_12xxxxLF
J3, J5: Conn_01x02; PinHeader_1x02_P2.54mm_Vertical
J4, J6: Conn_01x02; PinHeader_1x02_P2.00mm_Vertical
TP1: TestPoint_2Pole; TestPlot
U1: DM02

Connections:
3V3AUX: J1.B10, J2.7, J2.66
+3V3: J1.A9, J1.A10, J1.B8, J2.10, J2.11, J2.12, J2.13, J2.69, J2.70, J2.71, J2.72
+12V: C1.1, J1.A2, J1.A3, J1.B1, J1.B2, J1.B3, J2.61, J2.62, J2.63, J3.1, J4.1, TP1.1, U1.4
GND: C1.2, C2.2, C3.2, C4.2, J1.A4, J1.A12, J1.A15, J1.A18, J1.A20, J1.A23, J1.A24, J1.A27, J1.A28, J1.A31, J1.B4, J1.B7, J1.B13, J1.B16, J1.B18, J1.B21, J1.B22, J1.B25, J1.B26, J1.B29, J1.B32, J2.5, J2.6, J2.8, J2.9, J2.20, J2.21, J2.24, J2.25, J2.28, J2.29, J2.32, J2.33, J2.36, J2.37, J2.40, J2.41, J2.44, J2.45, J2.48, J2.49, J2.52, J2.53, J2.56, J2.57, J2.60, J2.64, J2.65, J2.67, J2.68, J2.73, J2.79, J2.82, J2.83, J2.86, J2.87, J2.90, J2.91, J2.94, J2.95, J2.98, J2.99, J2.102, J2.103, J2.106, J2.107, J2.110, J2.111, J2.114, J2.115, J2.118, J2.119, J3.2, J4.2, J5.2, J6.2, U1.2, U1.3
HSI0_N: J1.A17, J2.31
HSI0_P: J1.A16, J2.30
HSI1_N: J1.A22, J2.35
HSI1_P: J1.A21, J2.34
HSI2_N: J1.A26, J2.39
HSI2_P: J1.A25, J2.38
HSI3_N: J1.A30, J2.43
HSI3_P: J1.A29, J2.42
HSO0_N: J1.B15, J2.89
HSO0_P: J1.B14, J2.88
HSO1_N: J1.B20, J2.93
HSO1_P: J1.B19, J2.92
HSO2_N: J1.B24, J2.97
HSO2_P: J1.B23, J2.96
HSO3_N: J1.B28, J2.101
HSO3_P: J1.B27, J2.100
P5V_AUX: C2.1, C3.1, C4.1, J2.2, J2.3, J2.4, J5.1, J6.1, TP1.2, U1.1
PERST: J1.A11, J2.17
PRSNT1: J1.A1, J2.1
PRSNT2: J1.B31, J2.120
REFCLK+: J1.A13, J2.84
REFCLK-: J1.A14, J2.85
SMCLK: J1.B5, J2.18
SMDAT: J1.B6, J2.19
WAKE: J1.B11, J2.77

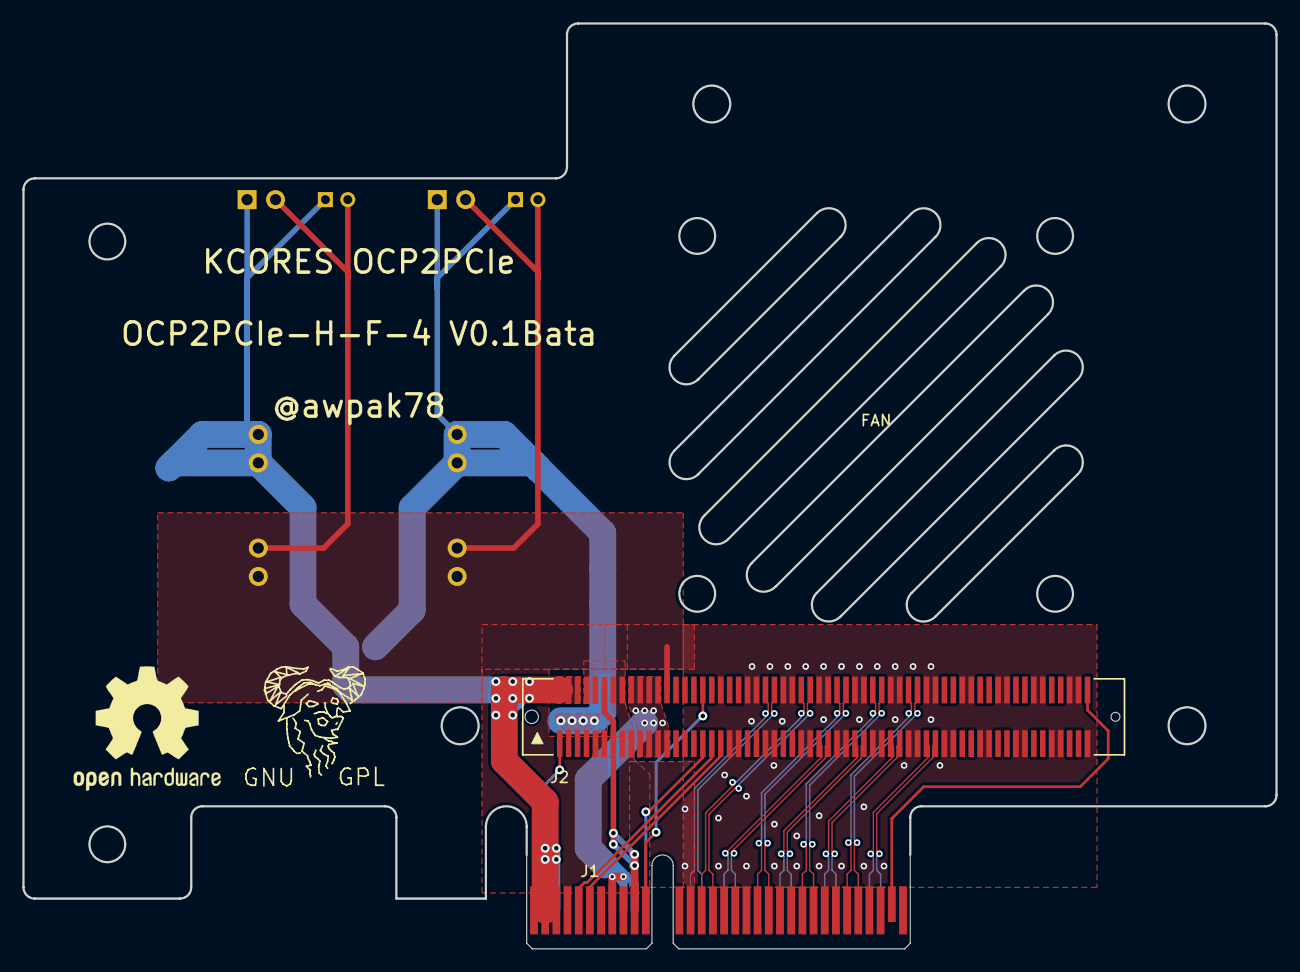
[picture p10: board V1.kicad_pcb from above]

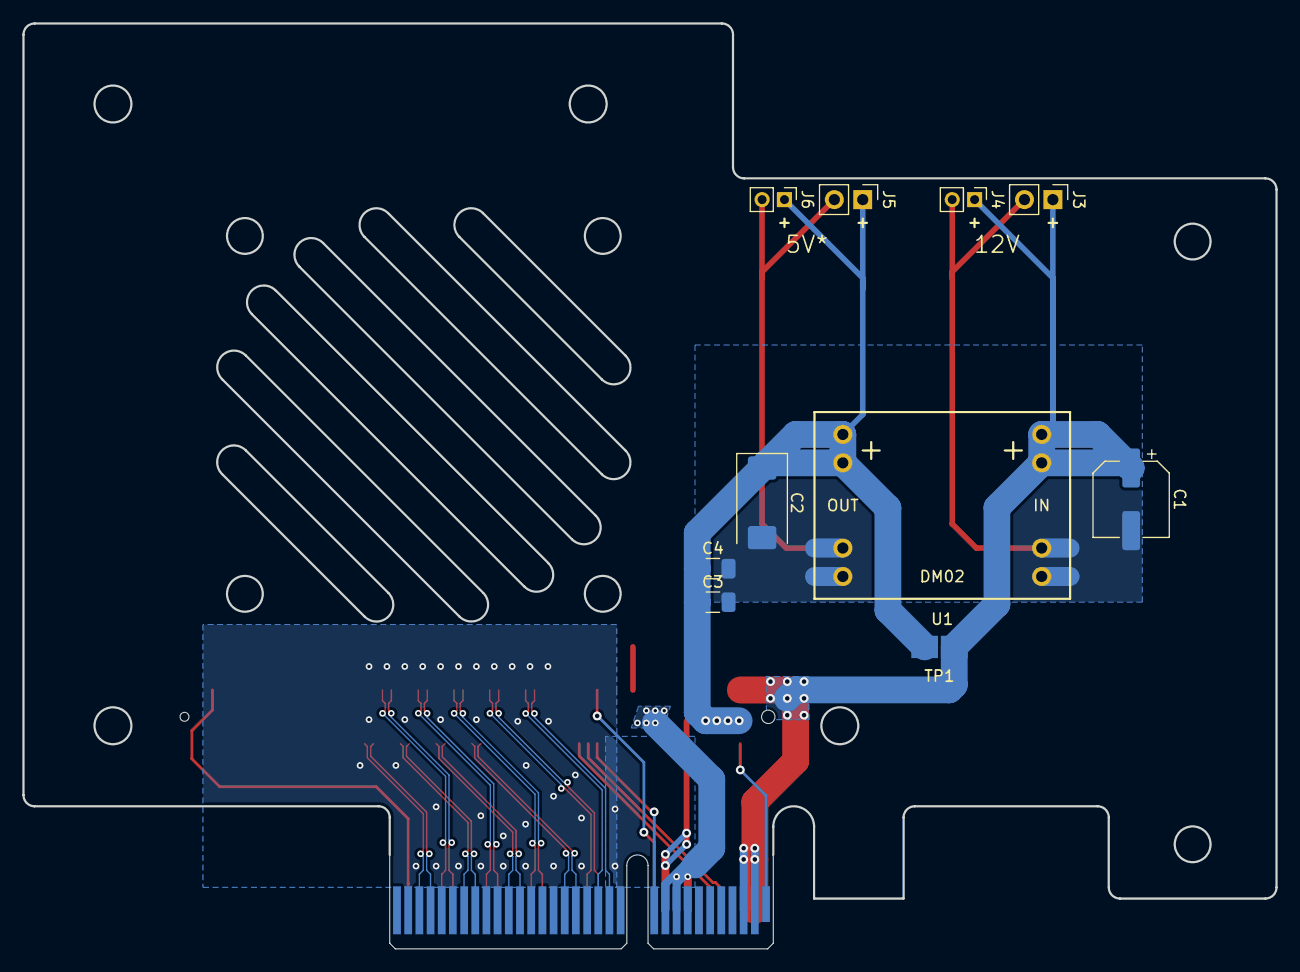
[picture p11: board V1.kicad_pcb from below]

Board: 2 copper layers, 112.1 x 82.8 mm, 13 parts (10 on the bottom side), 29 nets.

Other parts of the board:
FAN: Fan_4010
